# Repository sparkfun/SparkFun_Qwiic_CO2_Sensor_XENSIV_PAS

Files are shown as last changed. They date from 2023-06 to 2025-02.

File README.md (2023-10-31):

SparkFun Photoacoustic Spectroscopy CO2 Sensor - PASCO2V01 (Qwiic) 
========================================

SparkFun Photoacoustic Spectroscopy CO2 Sensor - PASCO2V01 (Qwiic) (https://www.sparkfun.com/products/22956)

[*SparkFun Photoacoustic Spectroscopy CO2 Sensor - PASCO2V01 (Qwiic) (SEN-22956)*](https://www.sparkfun.com/products/22956)

The SparkFun Photoacoustic Spectroscopy CO<sub>2</sub> Sensor features the XENSIV<sup>&trade;</sup> PASCO2V01 sensor package from Infineon<sup>&copy;</sup>. The sensor measures highly-accurate CO<sub>2</sub> data in direct parts-per-million (ppm) format over I<sup>2</sup>C, UART and PWM. The PAS CO2 employs a photoacoustic spectroscopy measurement system that combines narrow-band filtered IR light and a highly sensitive microphone inside the sensing cavity to measure CO<sub>2</sub> concentrations from 0 to 32,000 ppm with a best accuracy of &plusmn;(30ppm + 3%) when reading between 400 ppm and 5,000 ppm. It also includes a microcontroller that converts the data into direct ppm readout over any of the three communication interfaces. The IR emitter on the PAS CO2 requires a 12V supply so the board includes a AP3012 boost regulator with a series of decoupling capacitors to output a clean 12V from the 3.3V sourced through a Qwiic connection.

Repository Contents
-------------------

* **/Documentation** - Data sheets, additional product information
* **/Firmware** - Example code 
* **/Hardware** - Eagle design files (.brd, .sch)
* **/Production** - Production panel files (.brd)
* **/docs** -  Documentation files for the Photoacoustic Spectroscopy CO2 Sensor - PASCO2V01 (Qwiic) 

Documentation
--------------
* **[Library](https://github.com/Infineon/arduino-pas-co2-sensor)** - Arduino library for the XENSIV PAS CO2 Sensor.
* **[Hookup Guide](https://sparkfun.github.io/SparkFun_Qwiic_CO2_Sensor_XENSIV_PAS)** - Basic hookup guide for the Photoacoustic Spectroscopy CO2 Sensor - PASCO2V01 (Qwiic).

Product Versions
----------------
* [SEN-22956](https://www.sparkfun.com/products/22956) - Initial release of the SparkFun Photoacoustic Spectroscopy CO2 Sensor - PASCO2V01 (Qwiic) 

License Information
-------------------

This product is _**open source**_! 

Please review the LICENSE.md file for license information. 

If you have any questions or concerns on licensing, please contact technical support on our [SparkFun forums](https://forum.sparkfun.com/viewforum.php?f=152).

Distributed as-is; no warranty is given.

- Your friends at SparkFun.

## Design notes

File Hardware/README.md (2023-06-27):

SparkFun <PRODUCT NAME> Design Files
=====================================

The .sch and .brd files hare are Eagle CAD schematic and PCB design files from SparkFun Electronics.
A freeware version of Autodesk Eagle can be found [here](https://www.autodesk.com/products/eagle/free-download).

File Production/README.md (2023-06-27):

SparkFun <PRODUCT NAME> Production Files
=========================================

These are the production files SparkFun uses for printing PCBs.

License Information
-------------------
This product is open source! 

The hardware is released under [Creative Commons ShareAlike 4.0 International](https://creativecommons.org/licenses/by-sa/4.0/).

Please use, reuse, and modify these files as you see fit. Please maintain attribution to SparkFun Electronics and release anything derivative under the same license.

Distributed as-is; no warranty is given.

- Your friends at SparkFun.

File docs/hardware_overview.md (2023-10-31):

---
icon: material/cog
---

Let's take a closer look at the XENSIV™ PAS CO<sub>2</sub> sensor and other hardware present on this Qwiic breakout.

## XENSIV PAS CO2 Sensor

The XENSIV PAS CO2 sensor from Infineon utilizes a photoacoustic spectroscopy gas measurement system to accurately measure CO<sub>2</sub> concentration in a very stable sensing environment. 

<figure markdown>
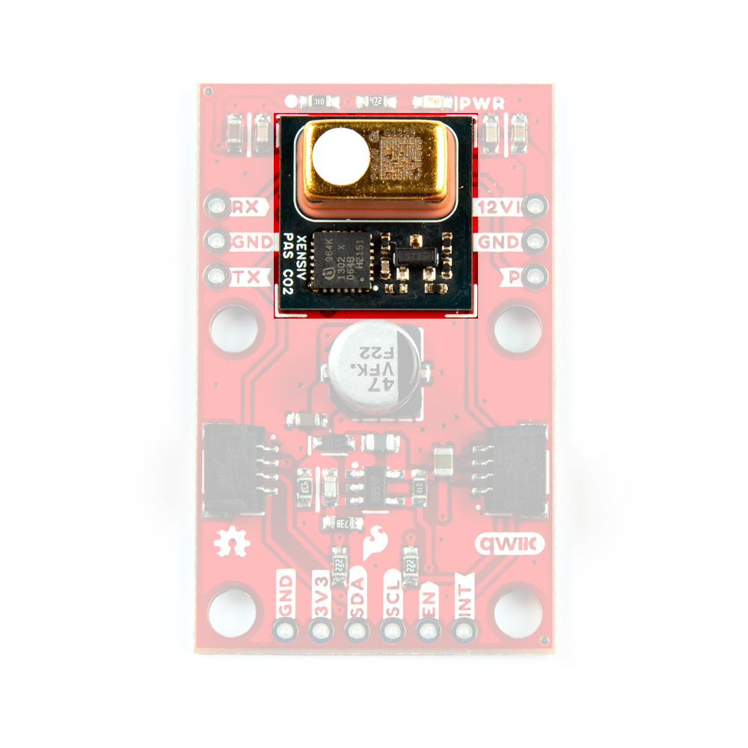
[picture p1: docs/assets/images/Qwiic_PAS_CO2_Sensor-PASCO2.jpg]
Highlighting PAS CO2 Sensor package.

</figure>

Photoacoustic spectroscopy uses a combination of narrow-band filtered IR light and MEMS microphone to measure CO<sub>2</sub> molecule concentration with high accuracy. The PAS CO<sub>2</sub> package includes an on-board microcontroller that parses the data recorded and converts it into direct parts per million (ppm) output to either UART, I<sup>2</sup>C, or pulse width modulation (PWM). For a complete overview of the PAS CO2, refer to the [datasheet](./assets/component_documentation/Infineon-PASCO2V01-DataSheet-v01_03-DataSheet-v01_03-EN.pdf).

You may be wondering what photoacoustic spectroscopy means. Photoacoustic measuring uses light (photo) and sound/vibrations (acoustic) in tandem to measure the the photoacoustic effect when energy is absorbed by particles. The sensor shines a specific frequency of IR light that CO<sub>2</sub> molecules absorb causing them to heat up, expand and release a pressure wave (sound) wave that the MEMS microphone picks up. This data is then processed and output in human-readable concentrations in PPM. This is just a quick and basic explanation of photoacoustic spectroscopy used in the PAS CO2 sensor. For detailed information, refer to Invensense's [product brief](https://www.infineon.com/cms/en/product/sensor/co2-sensors/#!?fileId=5546d4626b2d8e69016b69ba27c958c1) for the sensor.

The PAS CO2 has three operating modes: Idle, Continuous, and Single-Shot. In idle mode the sensor is inactive and does not take any measurements. In continuous mode the sensor takes periodic measurements and returns to idle once the measurement sequence finishes. The measurement period is configurable from anywhere between 5 to 4095 seconds. In single-shot mode the sensor enters a single measurement period and then returns to idle mode. 

<table>
    <tr>
        <th>Parameter</th>
        <th>Units</th>
        <th>Min</th>
        <th>Typ</th>
        <th>Max</th>
        <th>Notes</th>
    </tr>
    <tr>
        <td>CO<sub>2</sub> Output Range</td>
        <td>ppm</td>
        <td>0</td>
        <td>-</td>
        <td>32,000</td>
        <td></td>
    </tr>
    <tr>
        <td>CO<sub>2</sub> Measurement Accuracy</td>
        <td>ppm</td>
        <td>-</td>
        <td>&plusmn;(30 + 3%)</td>
        <td>-</td>
        <td>Accuracy when measuring between 400ppm and 5,000ppm.</td>
    </tr>
    <tr>
        <td>Ambient Temperature Range</td>
        <td>&deg;C</td>
        <td>0</td>
        <td>-</td>
        <td>50</td>
        <td></td>
    </tr>
    <tr>
        <td>Relative Humidity Range</td>
        <td>%RH</td>
        <td>0</td>
        <td>-</td>
        <td>85</td>
        </td></td>
    </tr>
    <tr>
        <td>CO<sub>2</sub> Sampling Time</td>
        <td>s</td>
        <td>5</td>
        <td>60</td>
        <td>4095</td>
        <td></td>
    </tr>
</table>

## Power & Boost Circuit

The PAS CO2 uses two input voltages, <b>12V</b> for the IR emitter and <b>3.3V</b> for the microcontroller and other components. This breakout has a AP3012 boost regulator to step up <b>3.3V</b> from the Qwiic connectors to <b>12V</b> along with a series of decoupling capacitors to ensure the IR emitter gets a clean supply voltage. The breakout also has PTH pins for both supply voltage if users prefer to power the sensor from a dedicated power supply. If you select this option, ensure both voltages fall within the supply range for each input (VDD3.3: <b>3V</b>-<b>3.6V</b> and VDD12: <b>10.8V</b>-<b>13.2V</b>).

## Communication Interfaces & Pinout

We designed this board to set the PAS CO2 to communicate by I<sup>2</sup>C by default but have included PTH pins for both the UART and PWM interfaces along with solder jumpers to enable/disable all three options.

<figure markdown>
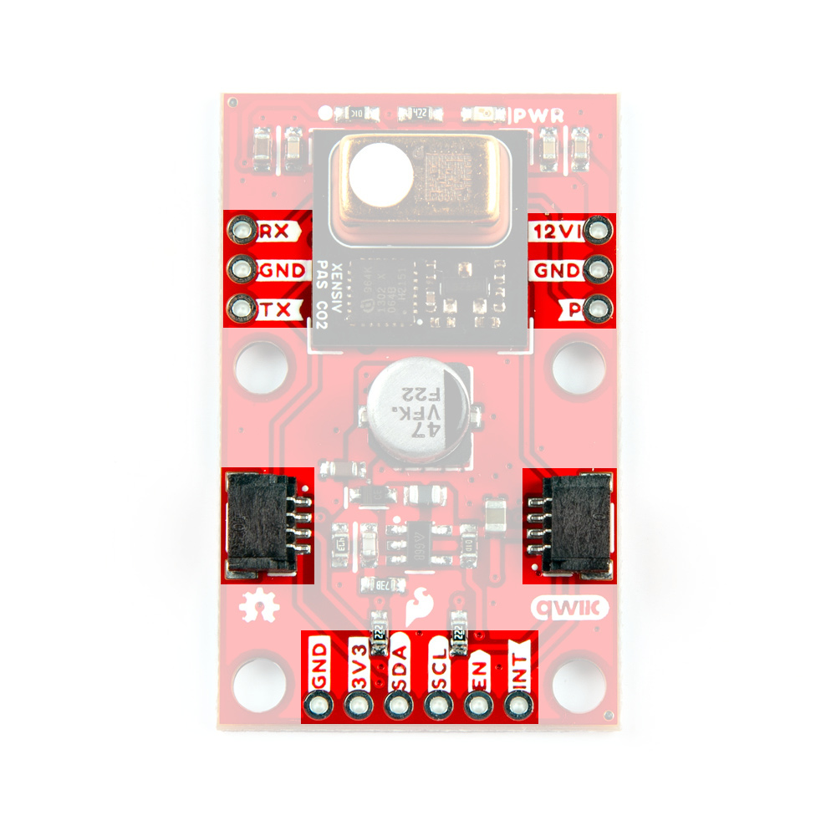
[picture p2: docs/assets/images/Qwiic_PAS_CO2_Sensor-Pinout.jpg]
Highlighting Qwiic and PTH headers.

</figure>

### Qwiic/I<sup>2</sup>C

The board routes the PAS CO2's I<sup>2</sup>C interface to a pair of Qwiic connectors as well as 0.1"-spaced plated through-hole (PTH) headers. This header also includes the PAS CO2's Interrupt pin, the AP3012 boost regulator's Enable pin, as well as connections to <b>3.3V</b> and <b>GND</b>. The PAS CO2's unshifted 7-bit I<sup>2</sup>C address is <b>0x28</b>.

The Interrupt pin can function as a standard hardware interrupt for alarm thresholds, data ready, and sensor busy statuses but also is configurable to act as an early measurement start notification. In this mode, the interrupt pin enters an active state (set to either active-high or active-low) roughly one second before a measurement period which can be tied to the enable pin for the LM62421 boost regulator. The interrupt turns this power supply on for roughly 0.2s at the start of the measurement period and again at the end. The design of the board has both this pin and the boost regulator's enable pin next to each other so users can tie them to each other to turn on the boost regulator just before measurement occurs to help conserve power.

### UART

The board routes the TX and RX pins to one side of the board along with a Ground PTH for voltage reference if needed. This interface is disabled by default and requires adjusting the PSEL jumper on the back of the board. Read on to the Solder Jumpers section for more information about enabling UART. 

### PWM

The PAS CO2's PWM interface is routed to the oppposite side of the board from the UART and also includes a Ground PTH for voltage reference. This interface is also disabled by default and can be enabled by adjusting the PWM jumper on the back of the board. Read on to the Solder Jumpers section for more information on enabling PWM output.

## Power LED

The lone LED on this board labeled <b>PWR</b> indicates when the <b>3.3V</b> circuit is powered.

<figure markdown>
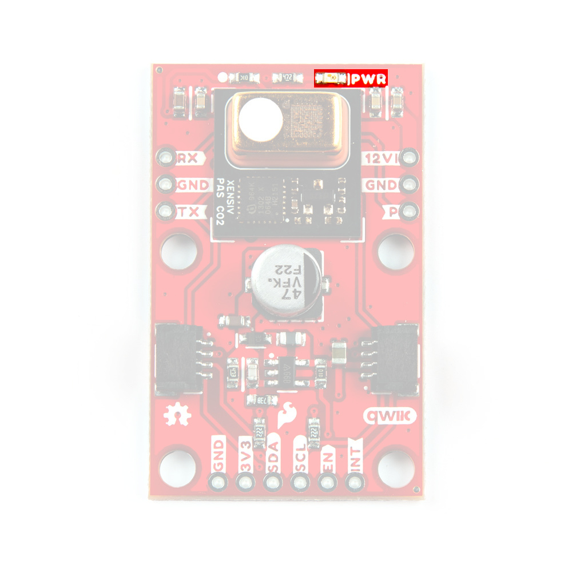
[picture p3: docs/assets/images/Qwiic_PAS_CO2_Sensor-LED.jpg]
Highlighting the Power LED.

</figure>

## Solder Jumpers

The breakout has four solder jumpers labeled <b>PWR</b>, <b>PSEL</b>, <b>PWM</b>, and <b>I<sup>2</sup>C</b>.

<figure markdown>
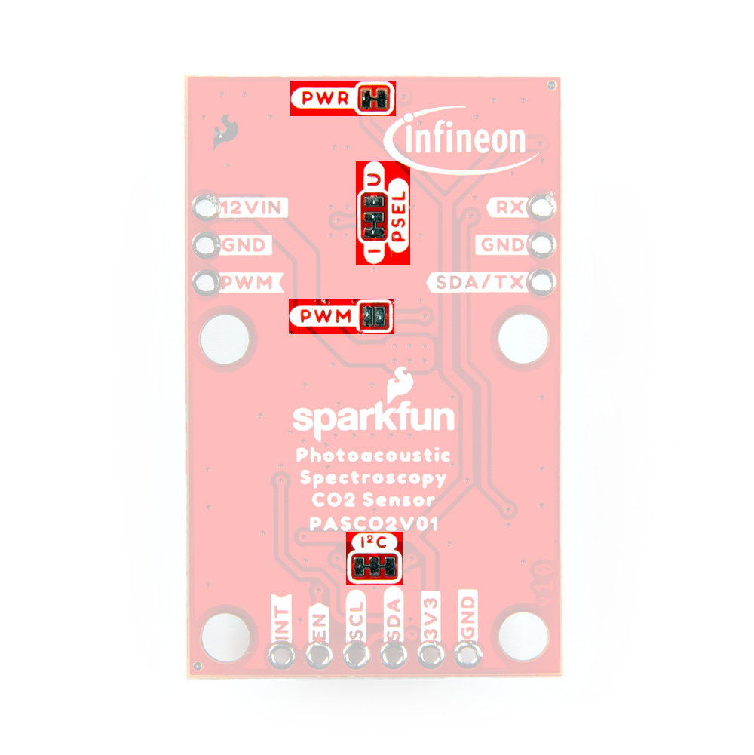
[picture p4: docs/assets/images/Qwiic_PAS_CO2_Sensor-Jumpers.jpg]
Highlighting the solder jumpers.

</figure>

* <b>PWR</b>: The PWR jumper completes the Power LED circuit. Open it to turn off the power LED to reduce the current draw of the board. 
* <b>PSEL</b>: The PSEL jumper is a three-way jumper that sets whether the PAS CO2 outputs over I<sup>2</sup>C (Default) or UART (Alternate). By default, the jumper pulls the PSEL line to Ground and enables the I<sup>2</sup>C interface indicated by the small "I" on the jumper. Severing the trace between the "I" pad and center pad and then connecting the center pad to the "U" pad switches the PAS CO2 to communicate over UART.
* <b>PWM</b>: The PWM jumper controls the PWM output through the PWM disable input pin. This jumper is OPEN by default to disable PWM through the internal pullup resistor. Close it to tie the PWM disable pin to ground and enable PWM output.
* <b>I</sup>2</sup>C</b>: Pulls the SDA/SCL lines to <b>3.3V</b> through a pair of 2.2k&ohm; resistors. Open the jumper completely to disable pullups on these lines if needed.

## Board Dimensions

This breakout measures in a bit larger than the Qwiic 1"x1" standard to accomidate the boost circuit for the IR emitter. The board measures 1"x1.6"(25.4mm x 40.64mm) with four mounting holes that fit a [4-40 screw](https://www.sparkfun.com/products/10453).

<figure markdown>
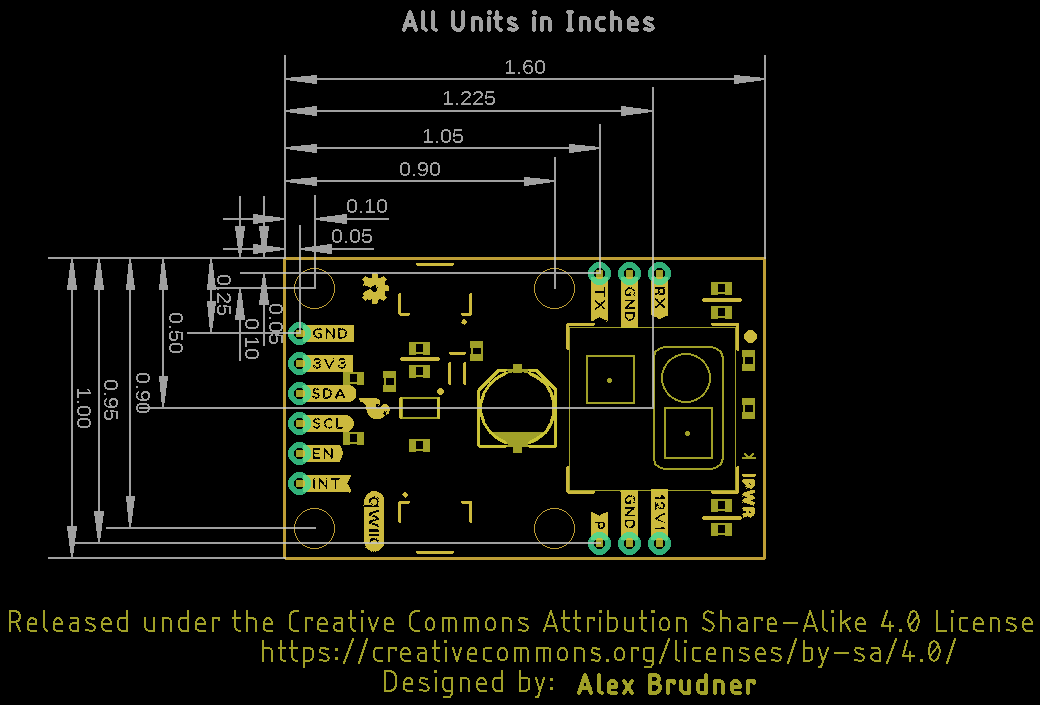
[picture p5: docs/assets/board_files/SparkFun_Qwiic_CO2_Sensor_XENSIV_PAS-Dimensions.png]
Board Dimensions.

</figure>

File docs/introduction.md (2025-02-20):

---
icon: material/book-open-page-variant
---

<div class="grid cards desc" markdown>

-    <a href="https://www.sparkfun.com/products/22956">
    **SparkFun Photoacoustic Spectroscopy CO<sub>2</sub> Sensor - PASCO2V01 (Qwiic)**<br>
    **SKU:** SEN-22956

    ---

    <figre markdown>
    Product Thumbnail
    </figure></a>

<!--
<center>
    <article class="video_desc">
    <iframe src="https://youtu.be/Du8RI4oUQT8?si=w0rP1W-pjiWIPvEG" title="Product Showcase: SparkFun Photoacoustic Spectroscopy CO<sub>2</sub> Sensor - PASCO2V01 (Qwiic)" frameborder="0" allow="accelerometer; autoplay; clipboard-write;encrypted-media; gyroscope; picture-in-picture" allowfullscreen></iframe>
    </article>
    </center>
-->
-    The SparkFun Photoacoustic Spectroscopy CO<sub>2</sub> Sensor - PASCO2V01 (Qwiic) is a breakout using the XENSIV<sup>&trade;</sup> PAS CO2 sensor package from Infineon<sup>&copy;</sup> which measures highly-accurate CO<sub>2</sub> concentrations and outputs data in direct parts-per-million (ppm) format over I<sup>2</sup>C, UART and PWN. The PAS CO2 employs a photoacoustic spectroscopy measurement system that combines narrow-band filtered IR light and a highly sensitive microphone inside the sensing cavity. The PAS CO2 measures CO<sub>2</sub> concentrations from 0 to 32,000ppm with a best accuracy of &plusmn;(30ppm +3%) when reading between 400 and 5,000ppm. It also includes and integrated microcontroller that processes and converts the data into direct ppm readout over any of the three communication interfaces. 
    This board includes a boost circuit to increase a 3.3V supply from the Qwiic connectors (or external) to 12V for the IR emitter supply voltage. This circuit includes a series of decoupling capacitors to output a clean 12V. We've also broken out all of the pins from the PAS CO2 package to 0.1"-spaced PTH headers so users have full access to all of the sensor's features.

    <center>
    [Purchase from SparkFun :fontawesome-solid-cart-plus:{ .heart }](https://www.sparkfun.com/products/22956){ .md-button .md-button--primary }
    </center>

</div>

In this guide we'll go over the hardware on this Qwiic breakout, how to assemble it into a circuit, and how to install and use Infineon's XENSIV PAS CO2 Arduino Library to configure and interact with the sensor.

## Required Materials

To follow along with this guide you will need a microcontroller to communicate with this breakout. Below are a few options that come Qwiic-enabled out of the box:

<div class="grid cards" markdown>

-   <a href="https://www.sparkfun.com/products/19177">

    <figure markdown>
    SparkFun IoT RedBoard - ESP32 Development Board
    </figure>
    </a>
    ---
    <a href="https://www.sparkfun.com/products/19177">
    **SparkFun IoT RedBoard - ESP32 Development Board**<br>
    DEV-20168
    </a>

-   <a href="https://www.sparkfun.com/products/18158">
    
    <figure markdown>
    SparkFun RedBoard Plus
    </figure>
    </a>
    ---
    <a href="https://www.sparkfun.com/products/18158">
    **SparkFun RedBoard Plus**<br>
    DEV-18158
    </a>

-   <a href="https://www.sparkfun.com/products/15574">
    
    <figure markdown>
    SparkFun Thing Plus - Artemis
    </figure>
    </a>
    ---
    <a href="https://www.sparkfun.com/products/15574">
    **SparkFun Thing Plus - Artemis**<br>
    DEV-18158
    </a>

-   <a href="https://www.sparkfun.com/products/20168">

    <figure markdown>
    SparkFun Thing Plus - ESP32 WROOM (USB-C)
    </figure>
    </a>
    ---
    <a href="https://www.sparkfun.com/products/20168">
    **SparkFun Thing Plus - ESP32 WROOM (USB-C)**<br>
    DEV-20168
    </a>
</div>

If your chosen microcontroller is not already Qwiic-enabled, you can add that functionality with one or more of the following items:

<div class="grid cards" markdown>

-   <a href="https://www.sparkfun.com/products/15081">

    <figure markdown>
    SparkFun Qwiic Cable Kit
    </figure>
    </a>
    ---
    <a href="https://www.sparkfun.com/products/15081">
    **SparkFun Qwiic Cable Kit**<br>
    KIT-15081
    </a>

-   <a href="https://www.sparkfun.com/products/14495">
    
    <figure markdown>
    SparkFun Qwiic Adapter
    </figure>
    </a>
    ---
    <a href="https://www.sparkfun.com/products/14495">
    **SparkFun Qwiic Adapter**<br>
    DEV-14495
    </a>

-   <a href="https://www.sparkfun.com/products/14352">
    
    <figure markdown>
    SparkFun Qwiic Shield for Arduino
    </figure>
    </a>
    ---
    <a href="https://www.sparkfun.com/products/14352">
    **SparkFun Qwiic Shield for Arduino**<br>
    DEV-14352
    </a>

-   <a href="https://www.sparkfun.com/products/16790">

    <figure markdown>
    SparkFun Qwiic Shield for Thing Plus
    </figure>
    </a>
    ---
    <a href="https://www.sparkfun.com/products/16790">
    **SparkFun Qwiic Shield for Thing Plus**<br>
    DEV-16790
    </a>
</div>

You will also need at least one Qwiic cable to connect your breakout to your microcontroller:

<div class="grid cards" markdown>

-   <a href="https://www.sparkfun.com/products/17259">

    <figure markdown>
    Flexible Qwiic Cable - 100mm)
    </figure>
    </a>
    ---
    <a href="https://www.sparkfun.com/products/17259">
    **Flexible Qwiic Cable - 100mm**<br>
    PRT-17259
    </a>

-   <a href="https://www.sparkfun.com/products/17260">
    
    <figure markdown>
    Qwiic Cable - 50mm
    </figure>
    </a>
    ---
    <a href="https://www.sparkfun.com/products/17260">
    **Flexible Qwiic Cable - 50mm**<br>
    PRT-17260
    </a>

-   <a href="https://www.sparkfun.com/products/17257">
    
    <figure markdown>
    Flexible Qwiic Cable - 500mm
    </figure>
    </a>
    ---
    <a href="https://www.sparkfun.com/products/17257">
    **Flexible Qwiic Cable - 500mm**<br>
    PRT-17257
    </a>

-   <a href="https://www.sparkfun.com/products/17261">

    <figure markdown>
    Flexible Qwiic Cable - Female Jumper (4-pin)
    </figure>
    </a>
    ---
    <a href="https://www.sparkfun.com/products/17261">**Flexible Qwiic Cable - Female Jumper (4-pin)**<br>
    CAB-17261
    </a>
</div>

## Optional Materials

If you prefer a soldered connection for I<sup>2</sup>C, prefer to use either the UART or PWM interfaces, or want to follow along with the Early Measurments Example later in this guide, you may need some of the products listed below:

<div class="grid cards" markdown align="center">

-   <a href="https://www.sparkfun.com/products/116">

    <figure markdown>
    Break Away Headers - Straight)
    </figure>
    </a>
    ---
    <a href="https://www.sparkfun.com/products/116">
    **Break Away Headers - Straight**<br>
    PRT-00116
    </a>

-   <a href="https://www.sparkfun.com/products/14681">
    
    <figure markdown>
    SparkFun Beginner Tool Kit
    </figure>
    </a>
    ---
    <a href="https://www.sparkfun.com/products/14681">
    **SparkFun Beginner Tool Kit**<br>
    TOL-14681
    </a>

-   <a href="https://www.sparkfun.com/products/9200">
    
    <figure markdown>
    Hobby Knife
    </figure>
    </a>
    ---
    <a href="https://www.sparkfun.com/products/9200">
    **Hobby Knife**<br>
    TOL-09200
    </a>

-   <a href="https://www.sparkfun.com/products/14579">

    <figure markdown>
    Chip Quik No-Clean Flux Pen - 10mL
    </figure>
    </a>
    ---
    <a href="https://www.sparkfun.com/products/14579">**Chip Quik No-Clean Flux Pen - 10mL**<br>
    CAB-14579
    </a>
</div>

## Suggested Reading

We designed this board for integration into SparkFun's Qwiic connect system.  Click on the banner below to learn more about the [SparkFun Qwiic Connect System](https://www.sparkfun.com/qwiic).

<div style="text-align: center">
<table>
  <tr>
   <td>
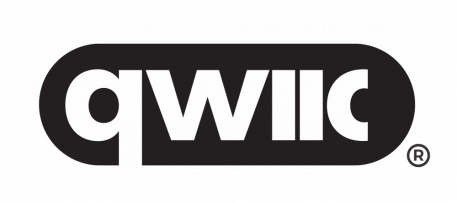
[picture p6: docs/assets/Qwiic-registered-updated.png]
Qwiic Connect System Click to learn more about the Qwiic Connect System!
   <div style="text-align: center"></div>
   </td>
  </tr>
  <tr>
    <td><div style="text-align: center"><i><a href="https://www.sparkfun.com/qwiic">Qwiic Connect System</a></i></div></td>
  </tr>
</table>
</div>

Before getting started with this Hookup Guide, you may want to read through the tutorials below if you are not familiar with the concepts covered in them or want a refresher. If you are using either of the Qwiic Shields linked above, we recommend reading through their respective Hookup Guides before continuing with this tutorial:

<div class="grid cards hide col-4" markdown align="center">

-   <a href="https://learn.sparkfun.com/tutorials/8">
    <figure markdown>
    Serial Communication
    </figure>
    </a>
    <a href="https://learn.sparkfun.com/tutorials/8">**Serial Communication**
    </a>

-   <a href="https://learn.sparkfun.com/tutorials/82">
    <figure markdown>
    I2C
    </figure>
    </a>
    <a href="https://learn.sparkfun.com/tutorials/82">**I2C**
    </a>

-   <a href="https://learn.sparkfun.com/tutorials/62">
    <figure markdown>
    Logic Levels
    </figure>
    </a>
    <a href="https://learn.sparkfun.com/tutorials/62">**Logic Levels**
    </a>

-   <a href="https://learn.sparkfun.com/tutorials/61">
    <figure markdown>
    Installing Arduino IDE
    </figure>
    </a>
    <a href="https://learn.sparkfun.com/tutorials/61">**Installing Arduino IDE**
    </a>

-   <a href="https://learn.sparkfun.com/tutorials/15">
    <figure markdown>
    Installing an Arduino Library
    </figure>
    </a>
    <a href="https://learn.sparkfun.com/tutorials/15">**Installing an Arduino Library**
    </a>

-   <a href="https://learn.sparkfun.com/tutorials/112">
    <figure markdown>
    Serial Terminal Basics
    </figure>
    </a>
    <a href="https://learn.sparkfun.com/tutorials/112">**Serial Terminal Basics**
    </a>

-   <a href="https://learn.sparkfun.com/tutorials/664">
    <figure markdown>
    How to Work with Jumper Pads and PCB Traces
    </figure>
    </a>
    <a href="https://learn.sparkfun.com/tutorials/664">**How to Work with Jumper Pads and PCB Traces**
    </a>

-   <a href="https://learn.sparkfun.com/tutorials/684">
    <figure markdown>
    Qwiic Shield for Arduino & Photon Hookup Guide
    </figure>
    </a>
    <a href="https://learn.sparkfun.com/tutorials/684">**Qwiic Shield for Arduino & Photon Hookup Guide**
    </a>

-   <a href="https://learn.sparkfun.com/tutorials/1107">
    <figure markdown>
    Qwiic Shield for Thing Plus Hookup Guide
    </figure>
    </a>
    <a href="https://learn.sparkfun.com/tutorials/1107">**Qwiic Shield for Thing Plus Hookup Guide**
    </a>
</div>

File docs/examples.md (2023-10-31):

---
icon: simple/arduino
---

## Example 1 - Continuous Mode

The first example demonstrates how to initialize the sensor over I<sup>2</sup>C to measure CO<sub>2</sub> data in Continuous Mode and print it out over serial. Open the example by navigating to <b>File</b> > <b>Examples</b> > <b>XENSIV PAS CO2</b> > <b> <b>continuous-mode</b>. After opening the example, select your Board and Port (in our case, SparkFun RedBoard IoT), and click "Upload". Open the [serial terminal](https://learn.sparkfun.com/tutorials/terminal-basics/arduino-serial-monitor-windows-mac-linux) with the baud set to <b>9600</b> and you should see the same as the screenshot below:

<figure markdown>
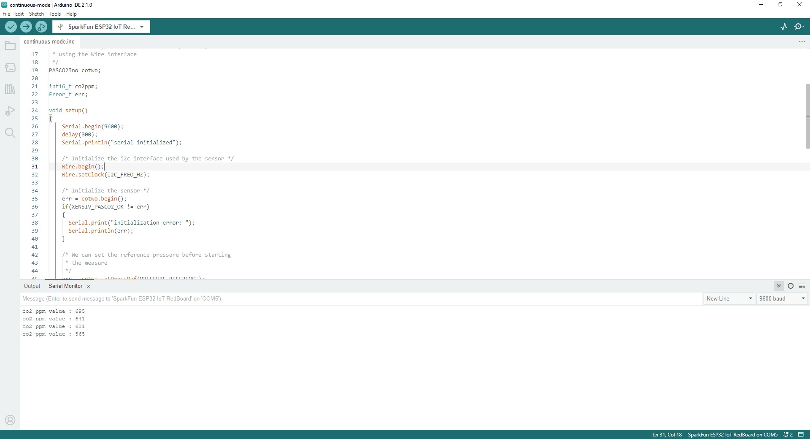
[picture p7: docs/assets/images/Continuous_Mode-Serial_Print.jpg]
Screenshot of serial printout from continuous mode example.

</figure>

## Example 2 - Boost Regulator Early Notification

The second example follows the assembly step in the Hardware Assembly section tying the PAS CO2's INT pin to the boost regulator's EN pin to control power for the regulator during measurements. This is a custom example we wrote so you'll need to get it from the [GitHub Repository](https://github.com/sparkfun/SparkFun_Qwiic_CO2_Sensor_XENSIV_PAS) or by copying the code below into a blank sketch:

??? "Early Measurement Example"

    ```
     --8<-- "https://raw.githubusercontent.com/sparkfun/SparkFun_Qwiic_CO2_Sensor_XENSIV_PAS/main/Firmware/Examples/Example01_EarlyMeasurementStartInterrupt/Example01_EarlyMeasur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"
    ```

Select your board and port and upload the example. After the uploade completes, open the serial terminal with the baud set to <b>115200</b> and you should see a printout similar to the one below with CO<sub>2</sub> measurements printing every ten seconds:

<figure markdown>
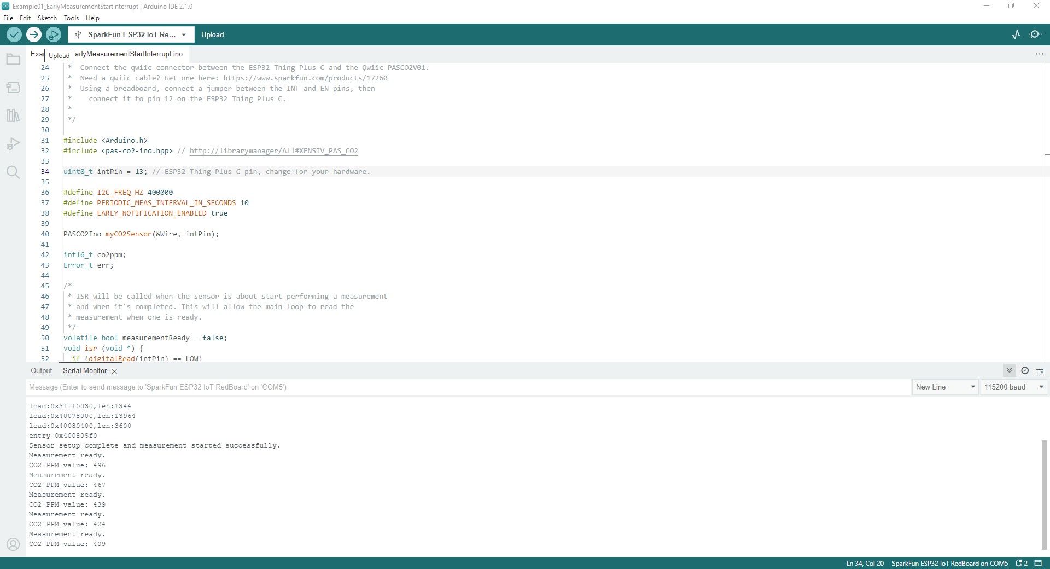
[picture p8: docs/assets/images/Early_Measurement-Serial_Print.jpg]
Screenshot of serial printout from early measurement example.

</figure>

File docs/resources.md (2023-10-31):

For more information about the XENSIV PAS CO2 sensor and this breakout, take a look at the resources below:

* [Schematic](./assets/board_files/SparkFun_Qwiic_CO2_Sensor_XENSIV_PAS.pdf)
* [Eagle Files](./assets/board_files/SparkFun_Qwiic_CO2_Sensor_XENSIV_PAS.zip)
* [Board Dimensions](./assets/board_files/SparkFun_Qwiic_CO2_Sensor_XENSIV_PAS-Dimensions.png)
* [Datasheet](./assets/component_documentation/Infineon-PASCO2V01-DataSheet-v01_03-DataSheet-v01_03-EN.pdf) (PASCO2V01)
* [Datasheet](./assets/component_documentation/AP3012.pdf) (AP3012 Boost Regulator)
* [Design-In Guidelines](./assets/component_documentation/Infineon-PAS_CO2_General_Design-In_Guideline.docx.-ApplicationNotes-v01_02-EN.pdf)
* [Low Power App Note](./assets/component_documentation/Infineon-XENSIV_PAS_CO2_lowpower_applications-ApplicationNotes-v01_01-EN.pdf)
* [PAS CO2 FCS & ABOC Compensation App Note](./assets/component_documentation/Infineon-AN_FCS_ABOC_XENSIV_PASCO2_2-ApplicationNotes-v01_04-EN.pdf)
* [GitHub Repository](https://github.com/sparkfun/SparkFun_Qwiic_CO2_Sensor_XENSIV_PAS)
* [XENSIV Arduino Library Repository](https://github.com/Infineon/arduino-pas-co2-sensor)

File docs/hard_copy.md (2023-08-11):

---
icon: fontawesome/solid/print
---

Need to download or print our hookup guide?

* [Print :fontawesome-solid-print:](../single_page) (Single-Page View)
    * To save as a `*.pdf` file, select the **Printer** or **Destination** labeled ++"Save as PDF"++. *(Instructions will vary based on the browser)*

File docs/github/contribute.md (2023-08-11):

# Help Improve the Experience!
Spot an improvement opportunity? Feel free to contribute to our open-source design and documentation. 

## Enhance our Documentation
All of this documentation can be modified by you! Please help us make it better.

* These pages are contained in the [`docs` folder](https://github.com/sparkfun/SparkFun_Qwiic_CO2_Sensor_XENSIV_PAS/tree/main/docs) of the [SparkFun Photoacoustic Spectroscopy CO<sub>2</sub> Sensor - PASCO2V01 (Qwiic)](https://github.com/sparkfun/SparkFun_Qwiic_CO2_Sensor_XENSIV_PAS) repository.

### Submit a Correction
1. Fork this repo
2. Add your corrections or improvements to the markdown file
3. File a pull request with your changes, and enjoy making the ~~words~~ ~~worlds~~ world a better place.
	* Once received, the documentation specialist will automatically be notified.
	* We will review your suggested improvements to make sure they are correct and fit within our documentation standards.

## Upgrade our Hardware Design
All of our designs are open-source! Please help us make it better.

* Our board design files are contained in the [`Hardware` folder](https://github.com/sparkfun/SparkFun_Qwiic_CO2_Sensor_XENSIV_PAS/tree/main/Hardware) of the [SparkFun Photoacoustic Spectroscopy CO<sub>2</sub> Sensor - PASCO2V01 (Qwiic)](https://github.com/sparkfun/SparkFun_Qwiic_CO2_Sensor_XENSIV_PAS) repository.

### Submit a Design Improvement
1. Fork this repo
2. Add your design modifications
3. File a pull request with your changes, and enjoy making the world a better place.
	* Once received, the engineer in charge of the original design will automatically be notified.
	* We will review your suggested upgrades, if they are within our board design standards and meet our product design requirements, we will flag these changes for our next board revision.
	
	!!! note
		Please note, that even if your suggestion is accepted, these changes may not be immediate. We may have to cycle through our current product inventory first.

## Contributors
Let's provide some recognition to those who have contributed to this project!

GitHub Contributors Image
<br>


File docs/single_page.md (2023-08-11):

---
hide:
  - navigation
  - toc
icon: fontawesome/solid/scroll
---

# Introduction
--8<-- "./docs/introduction.md:5"

# Hardware Overview
--8<-- "./docs/hardware_overview.md:5"

# Hardware Assembly
--8<-- "./docs/hardware_assembly.md:5"

# Software Setup and Programming
--8<-- "./docs/software_setup.md:5"

# Example Code
--8<-- "./docs/examples.md"

# Troubleshooting Tips
--8<-- "./docs/troubleshooting.md"

# Resources:
--8<-- "./docs/resources_and_going_further.md"

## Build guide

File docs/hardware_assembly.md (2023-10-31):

---
icon: material/tools
---

Now that we're familiar with the PAS CO2 sensor and other hardware on this breakout, it's time to assemble it into a circuit.

## Qwiic Assembly

SparkFun's Qwiic system makes assembling a circuit a breeze. Simply plug the breakout into your chosen microcontroller with a Qwiic cable. After assembling your circuit, it should look similar to the photo below:

<figure markdown>
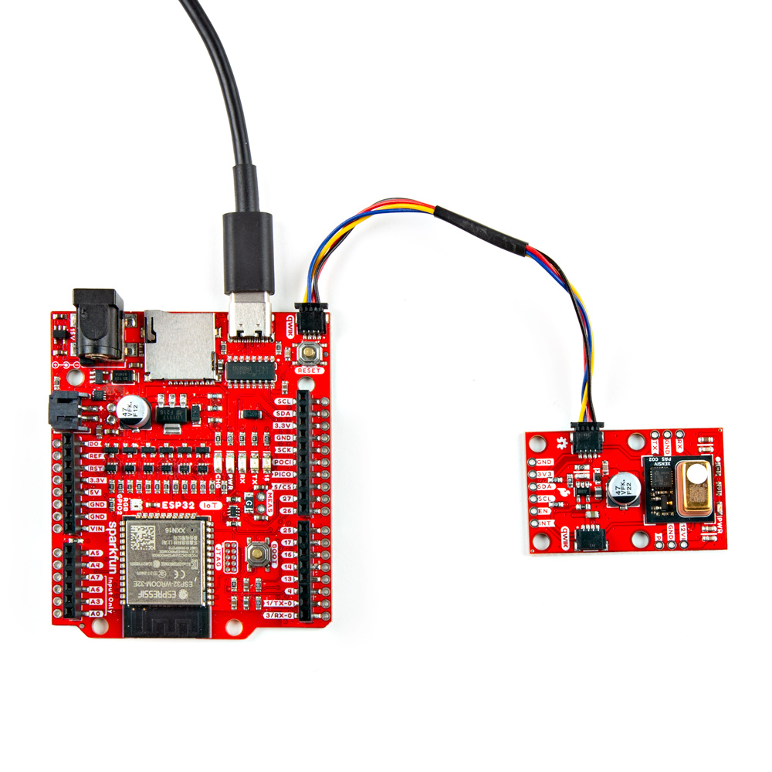
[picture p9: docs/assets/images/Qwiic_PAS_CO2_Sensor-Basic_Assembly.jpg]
Simple Qwiic circuit assembled with IoT RedBoard.

</figure>

## Soldered Assembly

Those who prefer to use either the UART or PWM interfaces or the other pins broken out on this board should solder wires or header pins to the PTH pins on the side of the board. If you're not familiar with through-hole soldering or would like a refresher, take a look at our Through-Hole Soldering Tutorial:

<div class="grid cards" markdown align="center">

-   <a href="https://learn.sparkfun.com/tutorials/5">
    <figure markdown>
    How to Solder: Through-Hole Soldering
    </figure>
    </a>
    <a href="https://learn.sparkfun.com/tutorials/5">**How to Solder: Through-Hole Soldering**
    </a>

</div>

### Boost Regulator Interrupt Assembly

The Early Measurement example in the Examples section demonstrates how to use the PAS CO2's Interrupt pin as an early measurement signal to control the boost regulator's power during measurement periods. If you want to follow along with that example you'll need to tie the INT PTH pin and EN PTH pin together. We recommend a set of [headers](https://www.sparkfun.com/products/12693) to these PTHs and bridge the EN and INT pins together using a jumper like [this](https://www.sparkfun.com/products/9044). You can also create a temporary connection between these pins with some alligator clips or through some wiring on a breadboard.

Next, connect the INT pin on the PAS CO<sub>2</sub> sensor breakout to an [interrupt capable pin]() on your development board. The example assumes the use of an ESP32 development board and sets pin 13 so adjust the wiring and code if necessary. With everything wired up on a [breadboard](), the circuit should look something similar to the photo below:

<figure markdown>
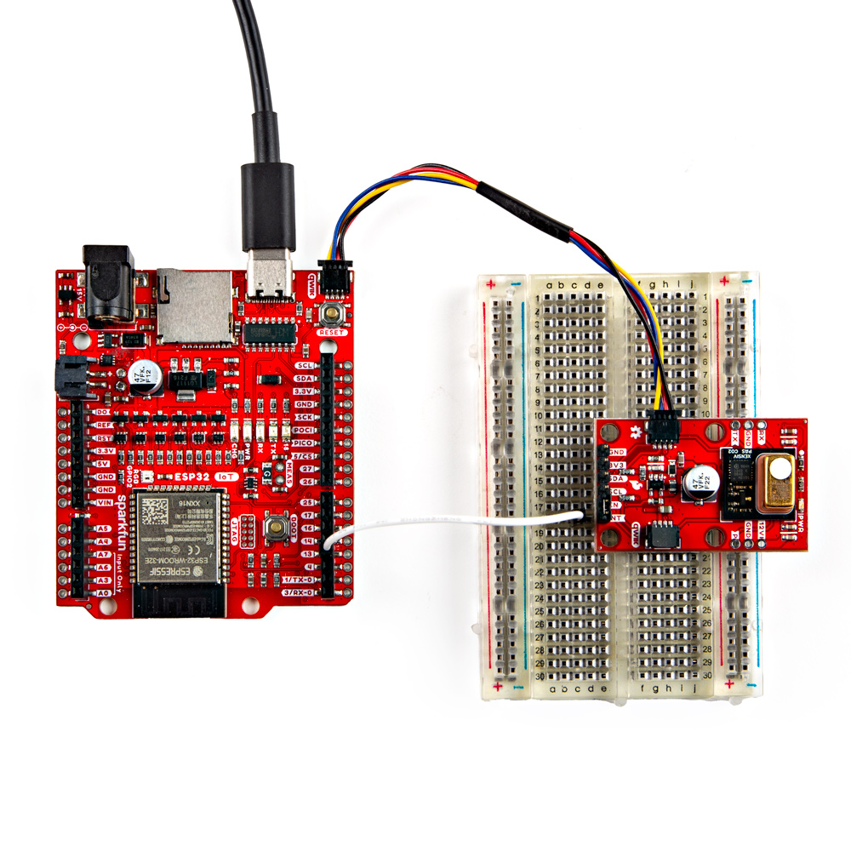
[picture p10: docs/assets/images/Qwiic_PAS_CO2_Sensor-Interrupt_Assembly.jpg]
Early measurement circuit assembly on a breadboard.

</figure>

## Calibration Procedure

The PASCO2V01 sensors require a week long calibration period, measuring every 10 seconds. During that period, the sensor *must* be outside for at least 30 minutes while taking measurements. Refer to the [Automatic baseline offset correction (ABOC) and forced compensation scheme (FCS)](./assets/component_documentation/Infineon-AN_FCS_ABOC_XENSIV_PASCO2_2-ApplicationNotes-v01_04-EN.pdf) application note for complete information about the calibration process. The graph below shows three sensors data outputs merge together during our calibration testing:

<figure markdown>
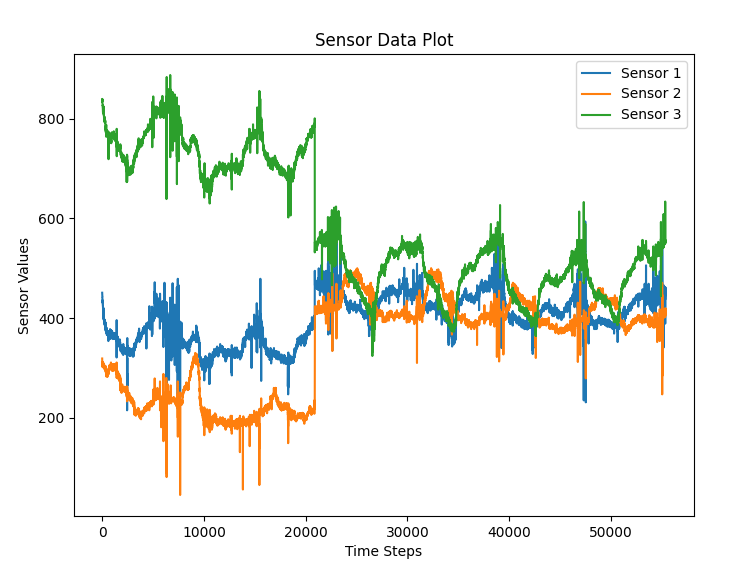
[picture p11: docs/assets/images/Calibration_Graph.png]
Sensor calibration graph.

</figure>

## Installation Recommendations

For ideal measurements, Infineon has several recommendations for installing the sensor in the final application found in this [application note](./assets/component_documentation/Infineon-PAS_CO2_General_Design-In_Guideline.docx.-ApplicationNotes-v01_02-EN.pdf). The list below outlines most of them but for complete information, refer to the app note linked above.

* Allow space above the sensor at least 12mm tall with a minimum opening size of 14mm x 14mm.
* Avoid direct airflow in front of the sensor.
* Isolate the sensor from ambient heat sources.
* Isolate the sensor from vibration sources.
* Avoid placing the sensor in direct sunlight.
* Prevent any condensation/water contact with the sensor.

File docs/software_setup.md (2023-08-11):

---
icon: simple/arduino
---

!!! attention
	If this is your first time using Arduino, please read through our tutorial on [installing the Arduino IDE](https://learn.sparkfun.com/tutorials/installing-arduino-ide). If you have not installed an Arduino library before, we recommend you check out our [installation guide](https://learn.sparkfun.com/tutorials/installing-an-arduino-library).

Infineon has written an Arduino Library for the PAS CO2 sensor to make it easy to get CO<sub>2</sub> data from the sensor along with other settings and features. Users can download the library through the Arduino Library Manager by searching for <b>"XENSIVE PAS CO2x"</b> as the screenshot below shows:

Those who prefer to manually install it can download a ZIP of the library from the [GitHub repository](https://github.com/Infineon/arduino-pas-co2-sensor) or by clicking the button below:

<center>
[XENSIV PAS CO2 Arduino Library (ZIP)](https://github.com/Infineon/arduino-pas-co2-sensor/archive/refs/heads/master.zip){ .md-button .md-button--primary }
</center>

With the library installed let's move on to looking at a few of the examples included in it.

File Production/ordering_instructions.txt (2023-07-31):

panel size, 169x96mm
PCB thickness, 1.6mm
number of layers, 2
material, TG155
soldermask color, Red
silkscreen color, White
oz copper, 1oz
finish, HASL lead free
stencils, top
pcs per panel, 12
min trace width, 0.1778mm / 0.0070in
min drill size, 0.3810mm / 0.0150in

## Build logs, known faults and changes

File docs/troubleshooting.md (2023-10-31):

## Ideal Installation Recommendations

For ideal measurements, Infineon has several recommendations for installing the sensor in the final application found in this [application note](). The list below outlines most of them but for complete information, refer to the app note linked above.

* Allow a space above the sensor at least 12mm tall with a minimum opening size of 14mm x 14mm.
* Avoid direct airflow in front of the sensor.
* Isolate the sensor from ambient heat sources.
* Isolate the sensor from vibration sources.
* Avoid placing the sensor in direct sunlight.
* Prevent any condensation/water contact with the sensor.

## Calibration Procedure

The PASCO2V01 sensors require a week long calibration period, measuring every 10 seconds. During that period, the sensor *must* be outside for at least 30 minutes while taking measurements. Refer to the [Automatic baseline offset correction (ABOC) and forced compensation scheme (FCS)](./assets/component_documentation/Infineon-AN_FCS_ABOC_XENSIV_PASCO2_2-ApplicationNotes-v01_04-EN.pdf) application note for complete information about the calibration process. The graph below shows three sensors data outputs merge together during our calibration testing:

<figure markdown>
Sensor calibration graph.
</figure>

## General Troubleshooting

!!! warning "Need Help?"
    If you need technical assistance or more information on a product that is not working as you expected, we recommend heading on over to the [SparkFun Technical Assistance](https://www.sparkfun.com/technical_assistanc) page for some initial troubleshooting.

    <center>
    [SparkFun Technical Assistance Page](https://www.sparkfun.com/technical_assistance){ .md-button .md-button--primary }
    </center>
    
    If you can't find what you need there, the [SparkFun Forums](https://forum.sparkfun.com/index.php) is a great place to search product forums and ask questions.
    
    !!! info "Account Registration Required"
        If this is your first visit to our forum, you'll need to create a [Forum Account](https://forum.sparkfun.com/ucp.php?mode=register) to post questions.

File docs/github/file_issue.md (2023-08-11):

# Did we make a mistake?

Spot something wrong? Please let us know. 

!!! attention
	This is not where customers should seek assistance on a product. If you require technical assistance or have questions about a product that is not working as expected, please head over to the [SparkFun Technical Assistance](https://www.sparkfun.com/technical_assistance) page for some initial troubleshooting.
    <center>
    [SparkFun Technical Assistance Page](https://www.sparkfun.com/technical_assistance){ .md-button .md-button--primary }
    </center>
    
    If you can't find what you need there, the [SparkFun Forums](https://forum.sparkfun.com/index.php) is a great place to search product forums and ask questions.
    
    !!! info "Account Registration Required"
        If this is your first visit to our forum, you'll need to create a [Forum Account](https://forum.sparkfun.com/ucp.php?mode=register) to search product forums and post questions.

## Discrepancies in the Documentation

All of this documentation can be modified by you! Please help us make it better.

* The documentation files for these pages are contained in the [`docs` folder](https://github.com/sparkfun/SparkFun_Qwiic_CO2_Sensor_XENSIV_PAS/tree/main/docs) of the [SparkFun Photoacoustic Spectroscopy CO<sub>2</sub> Sensor - PASCO2V01 (Qwiic)](https://github.com/sparkfun/SparkFun_Qwiic_CO2_Sensor_XENSIV_PAS) repository.

### Spot something wrong?
If a section of the documentation is incorrect, please [open an issue](https://github.com/sparkfun/SparkFun_Qwiic_CO2_Sensor_XENSIV_PAS/issues) and let us know.

### Do you have a suggested correction?
1. With a GitHub account, fork this repo
2. Add your correction(s) or improvement(s) to the markdown file(s)
3. File a pull request with your changes, and enjoy making the ~~words~~ ~~worlds~~ world a better place.
	* Once received, the documentation specialist will automatically be notified.
	* We will review your suggested improvement(s) to make sure they are correct and fit within our documentation standards.

## Problems in the Hardware Design

All of our designs are open-source! Please help us make it better.

* Our board design files are contained in the [`Hardware` folder](https://github.com/sparkfun/SparkFun_Qwiic_CO2_Sensor_XENSIV_PAS/tree/main/Hardware) of the [SparkFun Photoacoustic Spectroscopy CO<sub>2</sub> Sensor - PASCO2V01 (Qwiic)](https://github.com/sparkfun/SparkFun_Qwiic_CO2_Sensor_XENSIV_PAS) repository.

### Does something not make sense?
If part of the design is confusing, please [open an issue](https://github.com/sparkfun/SparkFun_Qwiic_CO2_Sensor_XENSIV_PAS/issues) and let us know.

### Did we forget to include an important function of the board?
* Please keep in mind that we may intentionally exclude certain functions of the board to meet our product design requirements. *(For example, our Qwiic Micro boards are intended to fit on a small board layout and only use I<sup>2</sup>C communication; therefore, we may not have the SPI and interrupt pins available for users.)*
* If part of the board's functionality is missing, please [open an issue](https://github.com/sparkfun/SparkFun_Qwiic_CO2_Sensor_XENSIV_PAS/issues) and file a feature request.

### Do you wish to contribute directly to improving the board design?
1. With a GitHub account, Fork this repo
2. Add your design improvement(s)
3. File a pull request with your changes, and enjoy making the ~~words~~ ~~worlds~~ world a better place.
	* Once received, the engineer in charge of the original design will automatically be notified.
	* We will review your suggested improvement(s), if they are within our board design standards and meet our product design requirements, we will flag these changes for our next board revision. *(Please note, that even if your suggestion is accepted, these changes may not be immediate. We may have to cycle through our current product inventory first.)*

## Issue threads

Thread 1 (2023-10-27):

Problem with format of Guides

ClarkInAz, 2023-10-27:
### Subject of the issue
Problem with overall format for Guides

### Your workbench
Firefox web browser on OSX
### Steps to reproduce
Look through the original guide by clicking on the "Getting Started" guide on https://www.sparkfun.com/products/22956
### Expected behavior
A clear explaination of HOW to get to the next page after the "background info" stuff.

### Actual behavior
FORCES first time user of this new Guide format to GUESS how to get to actual info.  Go look at one of the older "Getting Started" guides -- it's VERY CLEAR how to get to the next page!

For example, https://learn.sparkfun.com/tutorials/sparkfun-gps-rtk-dead-reckoning-zed-f9r-hookup-guide
It's BLATANTLY CLEAR how to get to the next page!

gigapod, 2023-10-30:
Hi @ClarkInAz,

Like many companies/individuals ([Arduino for example](https://arduino.github.io/arduino-cli/0.35/)) in the development board space, we’re moving to host our hookup guides/documentation on GitHub pages – using [Material MKDocs](https://squidfunk.github.io/mkdocs-material/) to generate our content.

The transition to a GitHub Pages solution provides SparkFun better tools to generate our documentation/content and more importantly reinforces our continued engagement and cooperation with the community as a whole – enabling rapid integration of community feedback, suggestions, and edits. This was difficult to impossible with our older system.

The documentation and content teams spent considerable effort in developing our new solution and are continuing to improve it going forward.

While the new solution does provide a “next page” indicator/link at the bottom of our documentation pages, your feedback is helpful for the teams as the continue to review our solution.

-Kirk

Closed 2023-10-30.

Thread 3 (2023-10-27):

Missing item in "Hardware Overview"

ClarkInAz, 2023-10-27:
### Subject of the issue
In the "Hardware Overview", under "Solder Jumpers", the I2C jumper is listed, but there's no explaination of what it does.

### Your workbench
Firefox on OSX

### Steps to reproduce
Read the "Solder Jumpers" section of the Guide.
### Expected behavior
The purpose of each of the four jumpers, PWR, PSEL, PWM, and I2C should have its own bullet describing what it does.

### Actual behavior
The bullet points for PWR, PSEL, and PWM are present, but the I2C is missing.
Although it's pretty typical that cutting the traces for the I2C disables the I2C pullup resistors, I don't have time right now to go through the schematic and verify it (not with the overhead of the new "comment" format), so won't submit a correction myself.

SFEMark, 2023-10-31:
Thanks for letting us know about this error. Your assumption is correct and it just pulls the SDA/SCL lines to 3.3V (but we all know what happens when you assume). We've updated the Hardware Overview section to add the I2C jumper description to the solder jumpers list.

Closed 2023-10-31.

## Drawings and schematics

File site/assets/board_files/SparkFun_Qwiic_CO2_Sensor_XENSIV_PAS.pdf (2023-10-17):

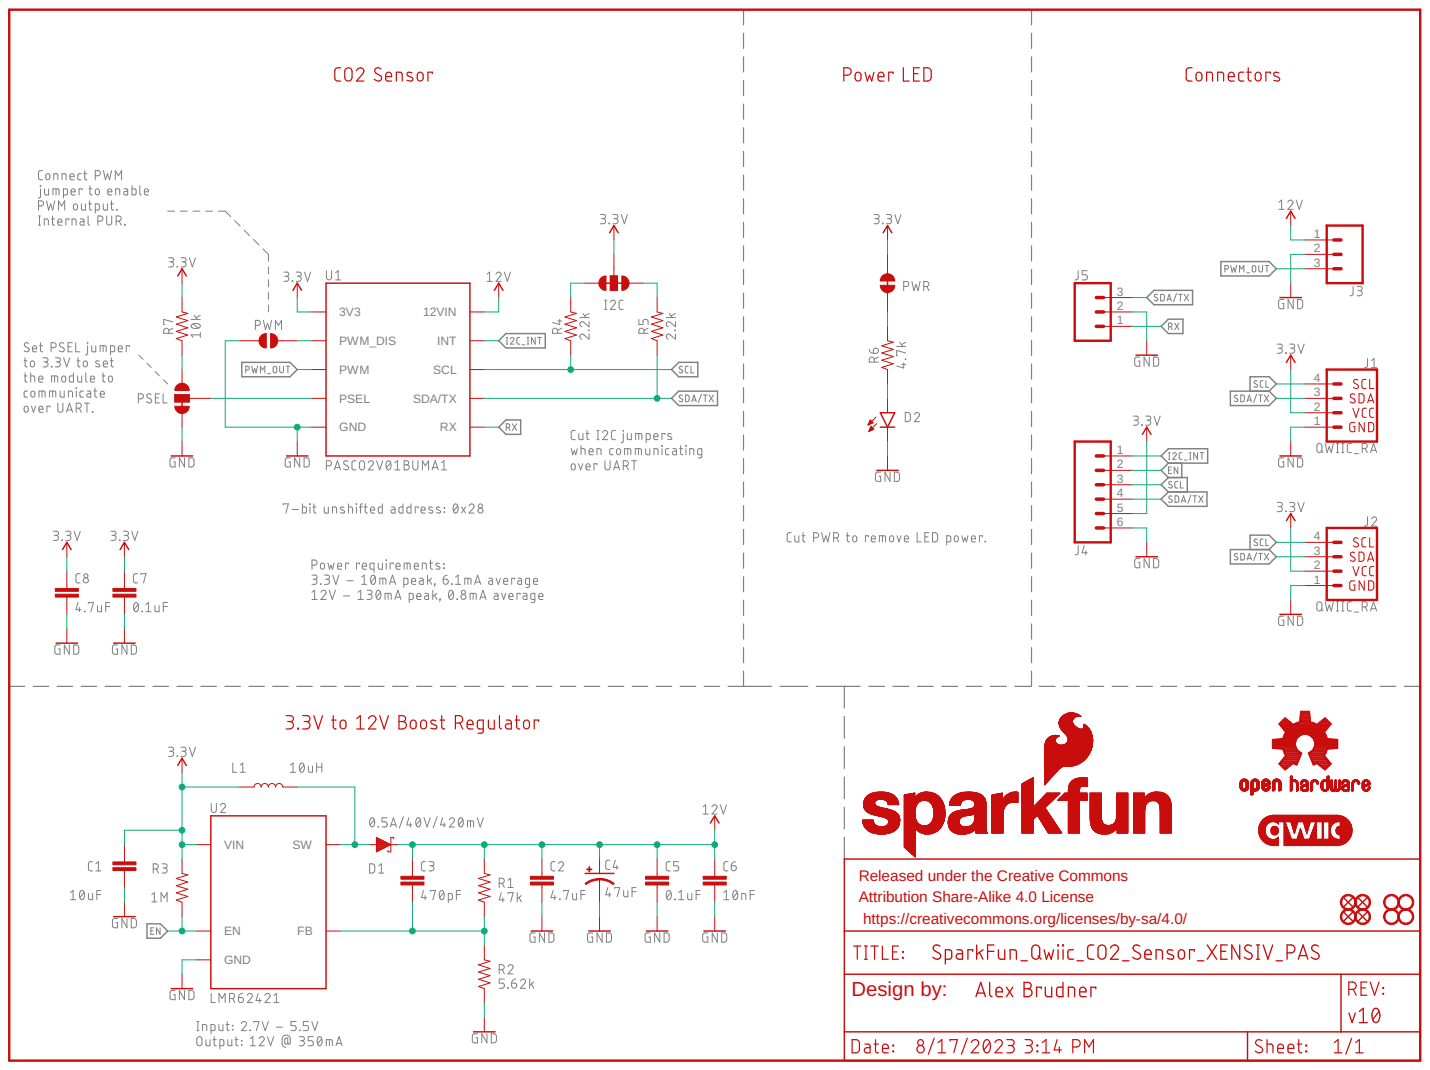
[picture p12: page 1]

INT SCL SDA/TXRX

Released under the Creative Commons Attribution Share-Alike 4.0 License

https://creativecommons.org/licenses/by-sa/4.0/

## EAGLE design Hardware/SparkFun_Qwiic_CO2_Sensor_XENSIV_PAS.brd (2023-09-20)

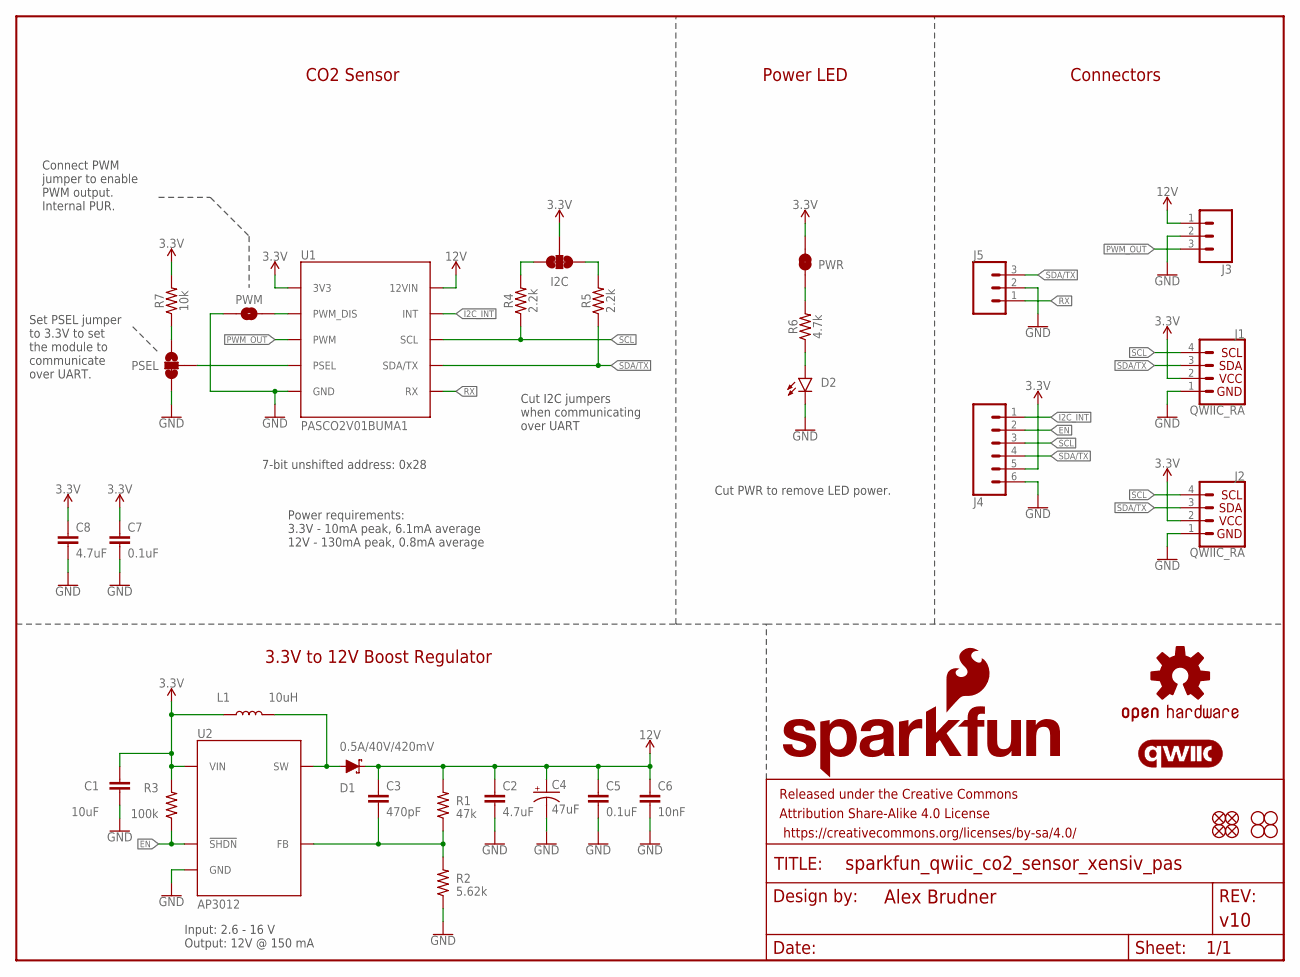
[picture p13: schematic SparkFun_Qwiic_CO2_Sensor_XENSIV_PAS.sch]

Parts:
C1: 10uF; 0805
C2, C8: 4.7uF; 0603
C3: 470pF; 0603
C4: 47uF; PANASONIC_D
C5, C7: 0.1uF; 0603
C6: 10nF; 0603
D1: 0.5A/40V/420mV; SOD-323
D2: LED-RED_0603-KB; LED-0603
FD1, FD2, FD3, FD4: FIDUCIALUFIDUCIAL; FIDUCIAL-MICRO
FRAME1: FRAME-LETTER; CREATIVE_COMMONS
H1, H2, H3, H4: STAND-OFF
I2C: JUMPER-SMT_3_2-NC_TRACE_SILK; SMT-JUMPER_3_2-NC_TRACE_SILK
J1, J2: QWIIC_RA; JST04_1MM_RA
J3, J5: CONN_031X03_NO_SILK; 1X03_NO_SILK
J4: CONN_06NO_SILK_NO_POP; 1X06_NO_SILK
L1: 10uH; 0805
LOGO1: SFE_LOGO_NAME_FLAME.1_INCH; SFE_LOGO_NAME_FLAME_.1
LOGO2: QWIIC_LOGO_5MM; QWIIC_5MM
LOGO3: OSHW-LOGOMINI; OSHW-LOGO-MINI
PSEL: JUMPER-SMT_3_1-NC_TRACE_SILK; SMT-JUMPER_3_1-NC_TRACE_SILK
PWM: JUMPER-SMT_2_NO_SILK; SMT-JUMPER_2_NO_SILK
PWR: JUMPER-SMT_2_NC_TRACE_SILK; SMT-JUMPER_2_NC_TRACE_SILK
R1: 47k; 0603
R2: 5.62k; 0603
R3: 100k; 0603
R4, R5: 2.2k; 0603
R6: 4.7k; 0603
R7: 10k; 0603
U1: PASCO2V01BUMA1; LG-MLGA-14-1_Z8B00206105
U2: AP3012; SOT95P280X145-5M

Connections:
3.3V: C1.1, C7.1, C8.1, I2C.2, J1.2, J2.2, J4.5, L1.1, PWR.2, R3.2, R7.2, U1.1 (3V3), U2.5 (VIN)
12V: C2.1, C3.1, C4.+, C5.1, C6.1, D1.C, J3.1, R1.2, U1.10 (12VIN)
EN: J4.2, R3.1, U2.4 (!SHDN!)
GND: C1.2, C2.2, C4.-, C5.2, C6.2, C7.2, C8.2, D2.C, J1.1, J2.1, J3.2, J4.6, J5.2, PSEL.3, PWM.1, R2.1, U1.6 (GND), U1.11 (GND), U1.12 (GND), U1.13 (GND), U1.14 (GND), U2.2 (GND)
I2C_INT: J4.1, U1.7 (INT)
unnamed: I2C.1, R5.2
unnamed: D1.A, L1.2, U2.1 (SW)
unnamed: I2C.3, R4.2
unnamed: C3.2, R1.1, R2.2, U2.3 (FB)
unnamed: PSEL.2, U1.8 (PSEL)
unnamed: D2.A, R6.1
unnamed: PWR.1, R6.2
unnamed: PSEL.1, R7.1
unnamed: PWM.2, U1.5 (PWM_DIS)
PWM_OUT: J3.3, U1.9 (PWM)
RX: J5.1, U1.2 (RX)
SCL: J1.4, J2.4, J4.3, R4.1, U1.3 (SCL)
SDA/TX: J1.3, J2.3, J4.4, J5.3, R5.1, U1.4 (SDA/TX)

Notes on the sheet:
3.3V to 12V Boost Regulator
CO2 Sensor
Connectors
Set PSEL jumper to 3.3V to set the module to communicate over UART.
Cut I2C jumpers when communicating over UART
Power LED
Cut PWR to remove LED power.
Input: 2.6 - 16 V Output: 12V @ 150 mA
7-bit unshifted address: 0x28
Power requirements: 3.3V - 10mA peak, 6.1mA average 12V - 130mA peak, 0.8mA average
Connect PWM jumper to enable PWM output. Internal PUR.

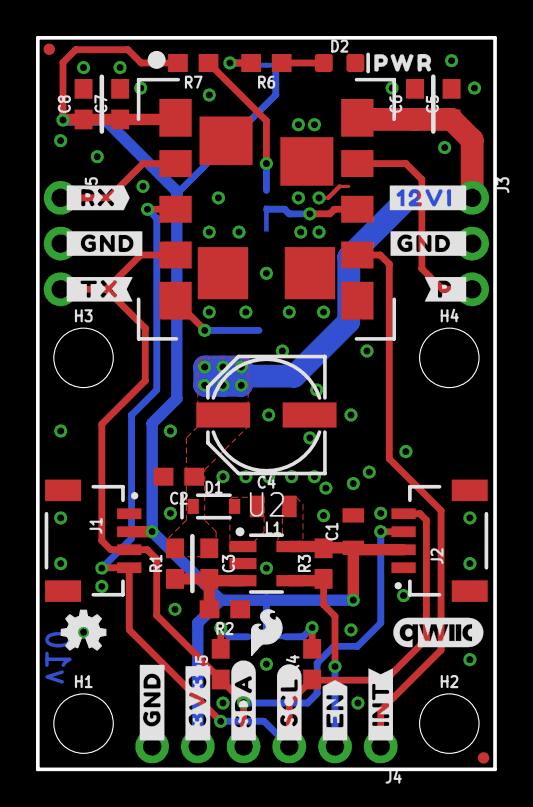
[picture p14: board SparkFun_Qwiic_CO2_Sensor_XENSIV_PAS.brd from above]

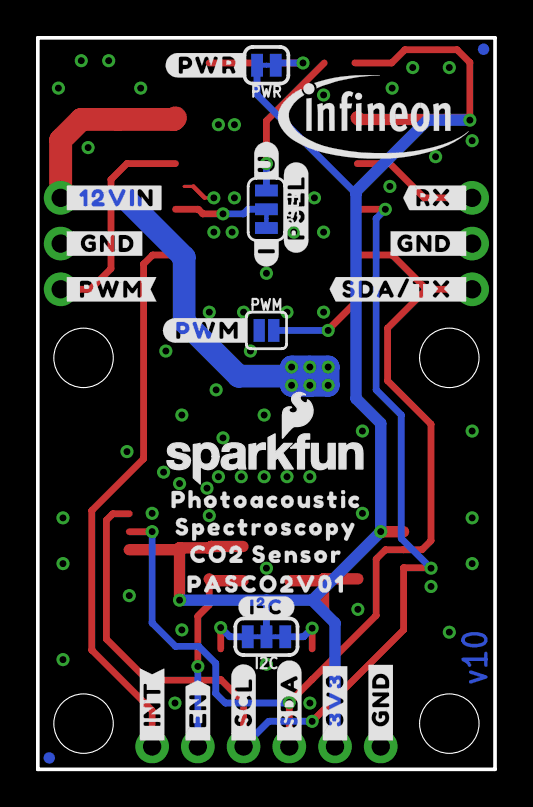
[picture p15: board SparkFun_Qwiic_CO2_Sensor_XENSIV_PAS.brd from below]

Board: 2 copper layers, 25.4 x 40.6 mm, 80 parts (31 on the bottom side), 18 nets.

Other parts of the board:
U$1: SFE_LOGO_FLAME_.1
U$2: #_12VIN#0
U$3, U$10: #_EN#0
U$4, U$5: #GND_#0
U$6: #_TX#0
U$7: #_RX#0
U$8, U$9, U$14, U$18: #_GND#0
U$11, U$19: #_3V3#0
U$12: #RX_#0
U$13: #SDA#TX_#0
U$15, U$36: #_SCL#0
U$16: #PWM#0
U$17: #P_#0
U$20, U$35: #_SDA#0
U$21, U$22: #_INT#0
U$23: INFINEON_LOGO
U$24: #PSEL#0
U$25: CO2_SENSOR0
U$26: SFE_LOGO_FLAME_STOP_.1
U$27: #I�C#0
U$28: #PWR#0
U$29: PWR0
U$30: ORDERING_INSTRUCTIONS
U$31: #I#0
U$32: #U#0
U$33: #12VI_#0
U$34: #_PWM#0
U$37: PHOTOACOUSTIC0
U$38: SPECTROSCOPY0
U$39: PASCO2V010

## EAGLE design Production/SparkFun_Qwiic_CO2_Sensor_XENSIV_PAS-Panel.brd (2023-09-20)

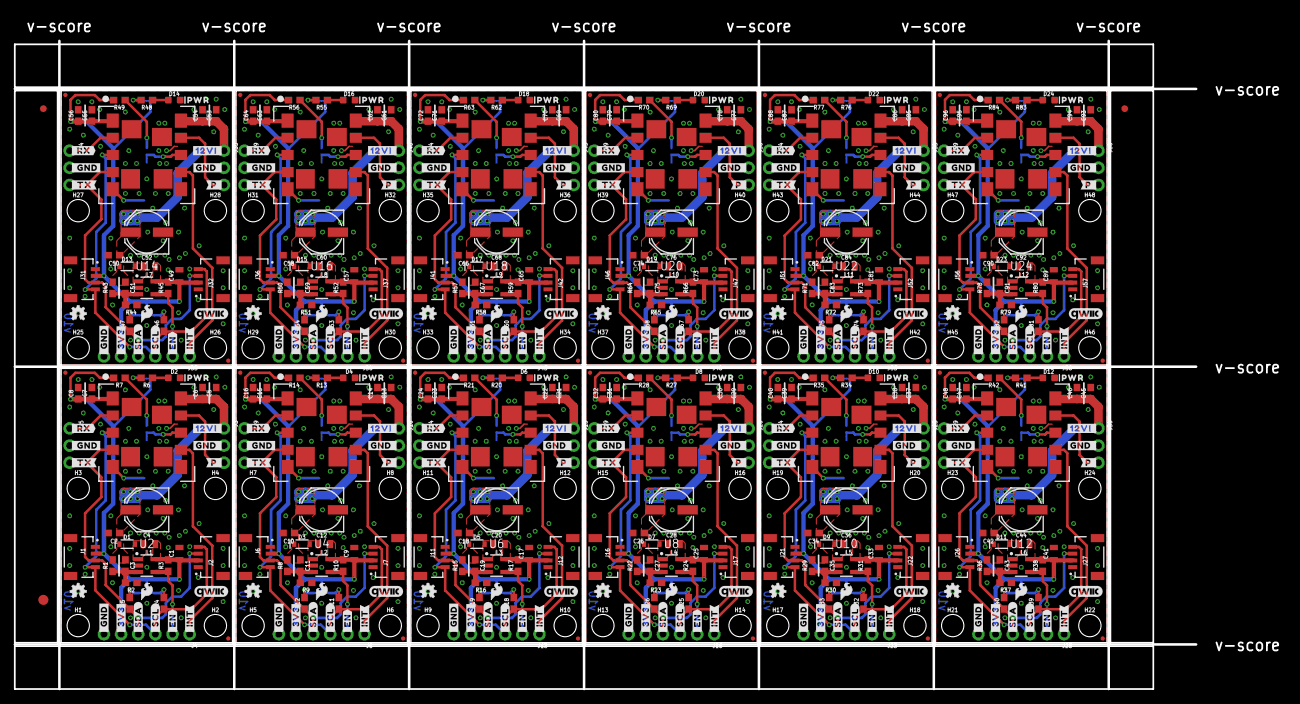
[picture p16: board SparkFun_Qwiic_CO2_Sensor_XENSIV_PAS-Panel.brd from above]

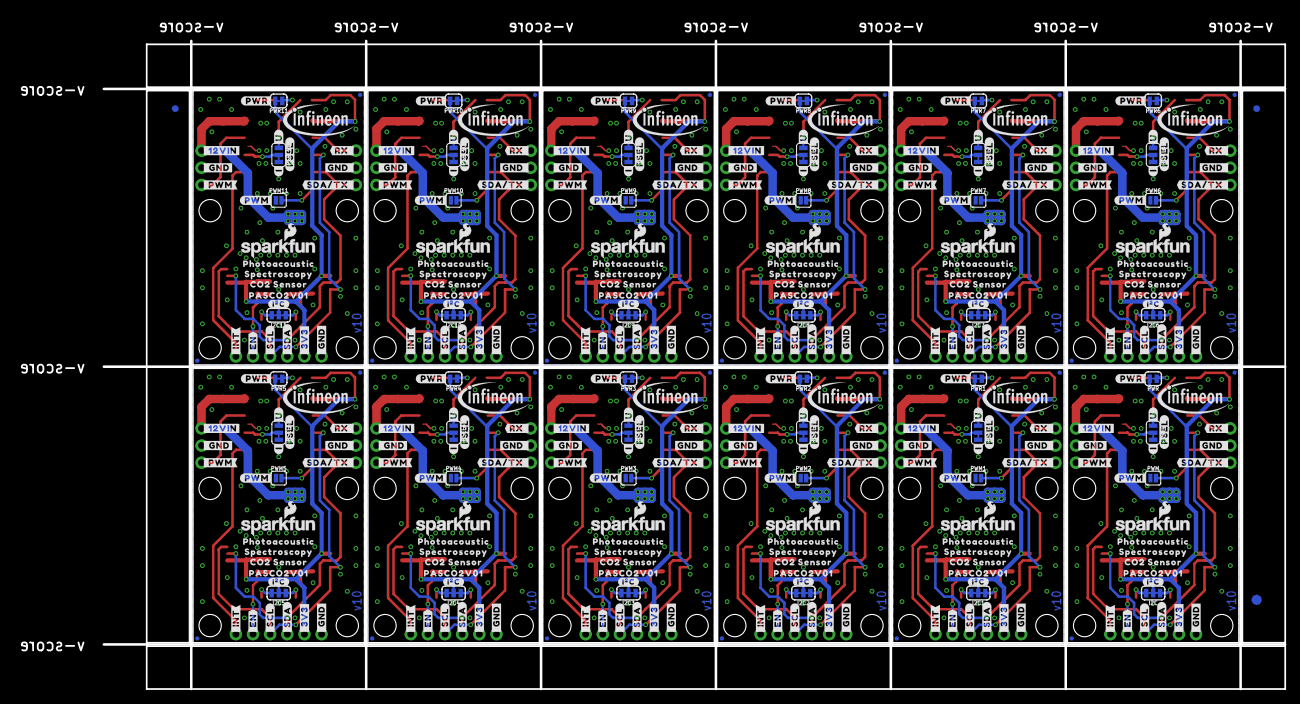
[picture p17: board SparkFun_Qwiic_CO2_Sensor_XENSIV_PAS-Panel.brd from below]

Board: 2 copper layers, 175.0 x 96.0 mm, 942 parts (375 on the bottom side), 216 nets.

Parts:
C1, C9, C17, C25, C33, C41, C49, C57, C65, C73, C81, C89: 10uF; 0805
C2, C8, C10, C16, C18, C24, C26, C32, C34, C40, C42, C48, C50, C56, C58, C64, C66, C72, C74, C80, C82, C88, C90, C96: 4.7uF; 0603
C3, C11, C19, C27, C35, C43, C51, C59, C67, C75, C83, C91: 470pF; 0603
C4, C12, C20, C28, C36, C44, C52, C60, C68, C76, C84, C92: 47uF; PANASONIC_D
C5, C7, C13, C15, C21, C23, C29, C31, C37, C39, C45, C47, C53, C55, C61, C63, C69, C71, C77, C79, C85, C87, C93, C95: 0.1uF; 0603
C6, C14, C22, C30, C38, C46, C54, C62, C70, C78, C86, C94: 10nF; 0603
D1, D3, D5, D7, D9, D11, D13, D15, D17, D19, D21, D23: 0.5A/40V/420mV; SOD-323
D2, D4, D6, D8, D10, D12, D14, D16, D18, D20, D22, D24: LED-0603
E$1, E$2, E$3, E$4: FIDUCIAL-1X2
E$5, E$6: FIDUCIAL-1.5X3
FD1, FD2, FD3, FD4, FD5, FD6, FD7, FD8, FD9, FD10, FD11, FD12, FD13, FD14, FD15, FD16, FD17, FD18, FD19, FD20, FD21, FD22, FD23, FD24, FD25, FD26, FD27, FD28, FD29, FD30, FD31, FD32, FD33, FD34, FD35, FD36, FD37, FD38, FD39, FD40, FD41, FD42, FD43, FD44, FD45, FD46, FD47, FD48: FIDUCIALUFIDUCIAL; FIDUCIAL-MICRO
H1, H2, H3, H4, H5, H6, H7, H8, H9, H10, H11, H12, H13, H14, H15, H16, H17, H18, H19, H20, H21, H22, H23, H24, H25, H26, H27, H28, H29, H30, H31, H32, H33, H34, H35, H36, H37, H38, H39, H40, H41, H42, H43, H44, H45, H46, H47, H48: STAND-OFF
I2C, I2C1, I2C2, I2C3, I2C4, I2C5, I2C6, I2C7, I2C8, I2C9, I2C10, I2C11: JUMPER-SMT_3_2-NC_TRACE_SILK; SMT-JUMPER_3_2-NC_TRACE_SILK
J1, J2, J6, J7, J11, J12, J16, J17, J21, J22, J26, J27, J31, J32, J36, J37, J41, J42, J46, J47, J51, J52, J56, J57: QWIIC_RA; JST04_1MM_RA
J3, J5, J9, J10, J14, J15, J19, J20, J24, J25, J29, J30, J34, J35, J39, J40, J44, J45, J49, J50, J54, J55, J59, J60: 1X03_NO_SILK
J4, J8, J13, J18, J23, J28, J33, J38, J43, J48, J53, J58: 1X06_NO_SILK
L1, L2, L3, L4, L5, L6, L7, L8, L9, L10, L11, L12: 10uH; 0805
LOGO1, LOGO4, LOGO7, LOGO10, LOGO13, LOGO16, LOGO19, LOGO22, LOGO25, LOGO28, LOGO31, LOGO34: SFE_LOGO_NAME_FLAME.1_INCH; SFE_LOGO_NAME_FLAME_.1
LOGO2, LOGO5, LOGO8, LOGO11, LOGO14, LOGO17, LOGO20, LOGO23, LOGO26, LOGO29, LOGO32, LOGO35: QWIIC_LOGO_5MM; QWIIC_5MM
LOGO3, LOGO6, LOGO9, LOGO12, LOGO15, LOGO18, LOGO21, LOGO24, LOGO27, LOGO30, LOGO33, LOGO36: OSHW-LOGOMINI; OSHW-LOGO-MINI
PSEL, PSEL1, PSEL2, PSEL3, PSEL4, PSEL5, PSEL6, PSEL7, PSEL8, PSEL9, PSEL10, PSEL11: JUMPER-SMT_3_1-NC_TRACE_SILK; SMT-JUMPER_3_1-NC_TRACE_SILK
PWM, PWM1, PWM2, PWM3, PWM4, PWM5, PWM6, PWM7, PWM8, PWM9, PWM10, PWM11: JUMPER-SMT_2_NO_SILK; SMT-JUMPER_2_NO_SILK
PWR, PWR1, PWR2, PWR3, PWR4, PWR5, PWR6, PWR7, PWR8, PWR9, PWR10, PWR11: JUMPER-SMT_2_NC_TRACE_SILK; SMT-JUMPER_2_NC_TRACE_SILK
R1, R8, R15, R22, R29, R36, R43, R50, R57, R64, R71, R78: 47k; 0603
R2, R9, R16, R23, R30, R37, R44, R51, R58, R65, R72, R79: 5.62k; 0603
R3, R10, R17, R24, R31, R38, R45, R52, R59, R66, R73, R80: 100k; 0603
R4, R5, R11, R12, R18, R19, R25, R26, R32, R33, R39, R40, R46, R47, R53, R54, R60, R61, R67, R68, R74, R75, R81, R82: 2.2k; 0603
R6, R13, R20, R27, R34, R41, R48, R55, R62, R69, R76, R83: 4.7k; 0603
R7, R14, R21, R28, R35, R42, R49, R56, R63, R70, R77, R84: 10k; 0603
U1, U3, U5, U7, U9, U11, U13, U15, U17, U19, U21, U23: PASCO2V01BUMA1; LG-MLGA-14-1_Z8B00206105
U2, U4, U6, U8, U10, U12, U14, U16, U18, U20, U22, U24: AP3012; SOT95P280X145-5M
U$1, U$30, U$77, U$115, U$153, U$191, U$229, U$267, U$305, U$343, U$381, U$419: SFE_LOGO_FLAME_.1
U$2, U$61, U$99, U$137, U$175, U$213, U$251, U$289, U$327, U$365, U$403, U$441: #_12VIN#0
U$3, U$10, U$62, U$63, U$100, U$101, U$138, U$139, U$176, U$177, U$214, U$215, U$252, U$253, U$290, U$291, U$328, U$329, U$366, U$367, U$404, U$405, U$442, U$443: #_EN#0
U$4, U$5, U$40, U$41, U$78, U$79, U$116, U$117, U$154, U$155, U$192, U$193, U$230, U$231, U$268, U$269, U$306, U$307, U$344, U$345, U$382, U$383, U$420, U$421: #GND_#0
U$6, U$42, U$80, U$118, U$156, U$194, U$232, U$270, U$308, U$346, U$384, U$422: #_TX#0
U$7, U$43, U$81, U$119, U$157, U$195, U$233, U$271, U$309, U$347, U$385, U$423: #_RX#0
U$8, U$9, U$14, U$18, U$44, U$45, U$48, U$50, U$82, U$83, U$86, U$88, U$120, U$121, U$124, U$126, U$158, U$159, U$162, U$164, U$196, U$197, U$200, U$202, U$234, U$235, U$238, U$240, U$272, U$273, U$276, U$278, U$310, U$311, U$314, U$316, U$348, U$349, U$352, U$354, U$386, U$387, U$390, U$392, U$424, U$425, U$428, U$430: #_GND#0
U$11, U$19, U$51, U$64, U$89, U$102, U$127, U$140, U$165, U$178, U$203, U$216, U$241, U$254, U$279, U$292, U$317, U$330, U$355, U$368, U$393, U$406, U$431, U$444: #_3V3#0
U$12, U$46, U$84, U$122, U$160, U$198, U$236, U$274, U$312, U$350, U$388, U$426: #RX_#0
U$13, U$47, U$85, U$123, U$161, U$199, U$237, U$275, U$313, U$351, U$389, U$427: #SDA#TX_#0
U$15, U$36, U$49, U$71, U$87, U$109, U$125, U$147, U$163, U$185, U$201, U$223, U$239, U$261, U$277, U$299, U$315, U$337, U$353, U$375, U$391, U$413, U$429, U$451: #_SCL#0
U$16, U$67, U$105, U$143, U$181, U$219, U$257, U$295, U$333, U$371, U$409, U$447: #PWM#0
U$17, U$65, U$103, U$141, U$179, U$217, U$255, U$293, U$331, U$369, U$407, U$445: #P_#0
U$20, U$35, U$69, U$70, U$107, U$108, U$145, U$146, U$183, U$184, U$221, U$222, U$259, U$260, U$297, U$298, U$335, U$336, U$373, U$374, U$411, U$412, U$449, U$450: #_SDA#0
U$21, U$22, U$52, U$53, U$90, U$91, U$128, U$129, U$166, U$167, U$204, U$205, U$242, U$243, U$280, U$281, U$318, U$319, U$356, U$357, U$394, U$395, U$432, U$433: #_INT#0
U$23, U$76, U$114, U$152, U$190, U$228, U$266, U$304, U$342, U$380, U$418, U$456: INFINEON_LOGO
U$24, U$54, U$92, U$130, U$168, U$206, U$244, U$282, U$320, U$358, U$396, U$434: #PSEL#0
U$25, U$74, U$112, U$150, U$188, U$226, U$264, U$302, U$340, U$378, U$416, U$454: CO2_SENSOR0
U$26, U$56, U$94, U$132, U$170, U$208, U$246, U$284, U$322, U$360, U$398, U$436: SFE_LOGO_FLAME_STOP_.1
U$27, U$55, U$93, U$131, U$169, U$207, U$245, U$283, U$321, U$359, U$397, U$435: #I�C#0
U$28, U$68, U$106, U$144, U$182, U$220, U$258, U$296, U$334, U$372, U$410, U$448: #PWR#0
U$29, U$57, U$95, U$133, U$171, U$209, U$247, U$285, U$323, U$361, U$399, U$437: PWR0
U$31, U$59, U$97, U$135, U$173, U$211, U$249, U$287, U$325, U$363, U$401, U$439: #I#0
U$32, U$58, U$96, U$134, U$172, U$210, U$248, U$286, U$324, U$362, U$400, U$438: #U#0
U$33, U$60, U$98, U$136, U$174, U$212, U$250, U$288, U$326, U$364, U$402, U$440: #12VI_#0
U$34, U$66, U$104, U$142, U$180, U$218, U$256, U$294, U$332, U$370, U$408, U$446: #_PWM#0
U$37, U$72, U$110, U$148, U$186, U$224, U$262, U$300, U$338, U$376, U$414, U$452: PHOTOACOUSTIC0
U$38, U$73, U$111, U$149, U$187, U$225, U$263, U$301, U$339, U$377, U$415, U$453: SPECTROSCOPY0
U$39, U$75, U$113, U$151, U$189, U$227, U$265, U$303, U$341, U$379, U$417, U$455: PASCO2V010

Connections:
3.3V: C1.1, C7.1, C8.1, I2C.2, J1.2, J2.2, J4.5, L1.1, PWR.2, R3.2, R7.2, U1.1, U2.5
3.3V1: C9.1, C15.1, C16.1, I2C1.2, J6.2, J7.2, J8.5, L2.1, PWR1.2, R10.2, R14.2, U3.1, U4.5
3.3V2: C17.1, C23.1, C24.1, I2C2.2, J11.2, J12.2, J13.5, L3.1, PWR2.2, R17.2, R21.2, U5.1, U6.5
3.3V3: C25.1, C31.1, C32.1, I2C3.2, J16.2, J17.2, J18.5, L4.1, PWR3.2, R24.2, R28.2, U7.1, U8.5
3.3V4: C33.1, C39.1, C40.1, I2C4.2, J21.2, J22.2, J23.5, L5.1, PWR4.2, R31.2, R35.2, U9.1, U10.5
3.3V5: C41.1, C47.1, C48.1, I2C5.2, J26.2, J27.2, J28.5, L6.1, PWR5.2, R38.2, R42.2, U11.1, U12.5
3.3V6: C49.1, C55.1, C56.1, I2C6.2, J31.2, J32.2, J33.5, L7.1, PWR6.2, R45.2, R49.2, U13.1, U14.5
3.3V7: C57.1, C63.1, C64.1, I2C7.2, J36.2, J37.2, J38.5, L8.1, PWR7.2, R52.2, R56.2, U15.1, U16.5
3.3V8: C65.1, C71.1, C72.1, I2C8.2, J41.2, J42.2, J43.5, L9.1, PWR8.2, R59.2, R63.2, U17.1, U18.5
3.3V9: C73.1, C79.1, C80.1, I2C9.2, J46.2, J47.2, J48.5, L10.1, PWR9.2, R66.2, R70.2, U19.1, U20.5
3.3V10: C81.1, C87.1, C88.1, I2C10.2, J51.2, J52.2, J53.5, L11.1, PWR10.2, R73.2, R77.2, U21.1, U22.5
3.3V11: C89.1, C95.1, C96.1, I2C11.2, J56.2, J57.2, J58.5, L12.1, PWR11.2, R80.2, R84.2, U23.1, U24.5
12V: C2.1, C3.1, C4.+, C5.1, C6.1, D1.C, J3.1, R1.2, U1.10
12V1: C10.1, C11.1, C12.+, C13.1, C14.1, D3.C, J10.1, R8.2, U3.10
12V2: C18.1, C19.1, C20.+, C21.1, C22.1, D5.C, J15.1, R15.2, U5.10
12V3: C26.1, C27.1, C28.+, C29.1, C30.1, D7.C, J20.1, R22.2, U7.10
12V4: C34.1, C35.1, C36.+, C37.1, C38.1, D9.C, J25.1, R29.2, U9.10
12V5: C42.1, C43.1, C44.+, C45.1, C46.1, D11.C, J30.1, R36.2, U11.10
12V6: C50.1, C51.1, C52.+, C53.1, C54.1, D13.C, J35.1, R43.2, U13.10
12V7: C58.1, C59.1, C60.+, C61.1, C62.1, D15.C, J40.1, R50.2, U15.10
12V8: C66.1, C67.1, C68.+, C69.1, C70.1, D17.C, J45.1, R57.2, U17.10
12V9: C74.1, C75.1, C76.+, C77.1, C78.1, D19.C, J50.1, R64.2, U19.10
12V10: C82.1, C83.1, C84.+, C85.1, C86.1, D21.C, J55.1, R71.2, U21.10
12V11: C90.1, C91.1, C92.+, C93.1, C94.1, D23.C, J60.1, R78.2, U23.10
EN: J4.2, R3.1, U2.4
EN1: J8.2, R10.1, U4.4
EN2: J13.2, R17.1, U6.4
EN3: J18.2, R24.1, U8.4
EN4: J23.2, R31.1, U10.4
EN5: J28.2, R38.1, U12.4
EN6: J33.2, R45.1, U14.4
EN7: J38.2, R52.1, U16.4
EN8: J43.2, R59.1, U18.4
EN9: J48.2, R66.1, U20.4
EN10: J53.2, R73.1, U22.4
EN11: J58.2, R80.1, U24.4
GND: C1.2, C2.2, C4.-, C5.2, C6.2, C7.2, C8.2, D2.C, J1.1, J2.1, J3.2, J4.6, J5.2, PSEL.3, PWM.1, R2.1, U1.6, U1.11, U1.12, U1.13, U1.14, U2.2
GND1: C9.2, C10.2, C12.-, C13.2, C14.2, C15.2, C16.2, D4.C, J6.1, J7.1, J8.6, J9.2, J10.2, PSEL1.3, PWM1.1, R9.1, U3.6, U3.11, U3.12, U3.13, U3.14, U4.2
GND2: C17.2, C18.2, C20.-, C21.2, C22.2, C23.2, C24.2, D6.C, J11.1, J12.1, J13.6, J14.2, J15.2, PSEL2.3, PWM2.1, R16.1, U5.6, U5.11, U5.12, U5.13, U5.14, U6.2
GND3: C25.2, C26.2, C28.-, C29.2, C30.2, C31.2, C32.2, D8.C, J16.1, J17.1, J18.6, J19.2, J20.2, PSEL3.3, PWM3.1, R23.1, U7.6, U7.11, U7.12, U7.13, U7.14, U8.2
GND4: C33.2, C34.2, C36.-, C37.2, C38.2, C39.2, C40.2, D10.C, J21.1, J22.1, J23.6, J24.2, J25.2, PSEL4.3, PWM4.1, R30.1, U9.6, U9.11, U9.12, U9.13, U9.14, U10.2
GND5: C41.2, C42.2, C44.-, C45.2, C46.2, C47.2, C48.2, D12.C, J26.1, J27.1, J28.6, J29.2, J30.2, PSEL5.3, PWM5.1, R37.1, U11.6, U11.11, U11.12, U11.13, U11.14, U12.2
GND6: C49.2, C50.2, C52.-, C53.2, C54.2, C55.2, C56.2, D14.C, J31.1, J32.1, J33.6, J34.2, J35.2, PSEL6.3, PWM6.1, R44.1, U13.6, U13.11, U13.12, U13.13, U13.14, U14.2
GND7: C57.2, C58.2, C60.-, C61.2, C62.2, C63.2, C64.2, D16.C, J36.1, J37.1, J38.6, J39.2, J40.2, PSEL7.3, PWM7.1, R51.1, U15.6, U15.11, U15.12, U15.13, U15.14, U16.2
GND8: C65.2, C66.2, C68.-, C69.2, C70.2, C71.2, C72.2, D18.C, J41.1, J42.1, J43.6, J44.2, J45.2, PSEL8.3, PWM8.1, R58.1, U17.6, U17.11, U17.12, U17.13, U17.14, U18.2
GND9: C73.2, C74.2, C76.-, C77.2, C78.2, C79.2, C80.2, D20.C, J46.1, J47.1, J48.6, J49.2, J50.2, PSEL9.3, PWM9.1, R65.1, U19.6, U19.11, U19.12, U19.13, U19.14, U20.2
GND10: C81.2, C82.2, C84.-, C85.2, C86.2, C87.2, C88.2, D22.C, J51.1, J52.1, J53.6, J54.2, J55.2, PSEL10.3, PWM10.1, R72.1, U21.6, U21.11, U21.12, U21.13, U21.14, U22.2
GND11: C89.2, C90.2, C92.-, C93.2, C94.2, C95.2, C96.2, D24.C, J56.1, J57.1, J58.6, J59.2, J60.2, PSEL11.3, PWM11.1, R79.1, U23.6, U23.11, U23.12, U23.13, U23.14, U24.2
I2C_INT: J4.1, U1.7
I2C_INT1: J8.1, U3.7
I2C_INT2: J13.1, U5.7
I2C_INT3: J18.1, U7.7
I2C_INT4: J23.1, U9.7
I2C_INT5: J28.1, U11.7
I2C_INT6: J33.1, U13.7
I2C_INT7: J38.1, U15.7
I2C_INT8: J43.1, U17.7
I2C_INT9: J48.1, U19.7
I2C_INT10: J53.1, U21.7
I2C_INT11: J58.1, U23.7
unnamed: I2C.1, R5.2
unnamed: D1.A, L1.2, U2.1
unnamed: I2C.3, R4.2
unnamed: C3.2, R1.1, R2.2, U2.3
unnamed: PSEL.2, U1.8
unnamed: D2.A, R6.1
unnamed: PWR.1, R6.2
unnamed: PSEL.1, R7.1
unnamed: PWM.2, U1.5
unnamed: D3.A, L2.2, U4.1
unnamed: C11.2, R8.1, R9.2, U4.3
unnamed: I2C1.1, R12.2
unnamed: I2C1.3, R11.2
unnamed: PSEL1.2, U3.8
unnamed: D4.A, R13.1
unnamed: PWR1.1, R13.2
unnamed: PSEL1.1, R14.1
unnamed: PWM1.2, U3.5
unnamed: D5.A, L3.2, U6.1
unnamed: C19.2, R15.1, R16.2, U6.3
unnamed: I2C2.1, R19.2
unnamed: I2C2.3, R18.2
unnamed: PSEL2.2, U5.8
unnamed: D6.A, R20.1
unnamed: PWR2.1, R20.2
unnamed: PSEL2.1, R21.1
unnamed: PWM2.2, U5.5
unnamed: D7.A, L4.2, U8.1
unnamed: C27.2, R22.1, R23.2, U8.3
unnamed: I2C3.1, R26.2
unnamed: I2C3.3, R25.2
unnamed: PSEL3.2, U7.8
unnamed: D8.A, R27.1
unnamed: PWR3.1, R27.2
unnamed: PSEL3.1, R28.1
unnamed: PWM3.2, U7.5
unnamed: D9.A, L5.2, U10.1
unnamed: C35.2, R29.1, R30.2, U10.3
unnamed: I2C4.1, R33.2
unnamed: I2C4.3, R32.2
unnamed: PSEL4.2, U9.8
unnamed: D10.A, R34.1
unnamed: PWR4.1, R34.2
unnamed: PSEL4.1, R35.1
unnamed: PWM4.2, U9.5
unnamed: D11.A, L6.2, U12.1
unnamed: C43.2, R36.1, R37.2, U12.3
unnamed: I2C5.1, R40.2
unnamed: I2C5.3, R39.2
unnamed: PSEL5.2, U11.8
unnamed: D12.A, R41.1
unnamed: PWR5.1, R41.2
unnamed: PSEL5.1, R42.1
unnamed: PWM5.2, U11.5
unnamed: D13.A, L7.2, U14.1
unnamed: C51.2, R43.1, R44.2, U14.3
unnamed: I2C6.1, R47.2
unnamed: I2C6.3, R46.2
unnamed: PSEL6.2, U13.8
unnamed: D14.A, R48.1
unnamed: PWR6.1, R48.2
unnamed: PSEL6.1, R49.1
unnamed: PWM6.2, U13.5
unnamed: D15.A, L8.2, U16.1
unnamed: C59.2, R50.1, R51.2, U16.3
unnamed: I2C7.1, R54.2
unnamed: I2C7.3, R53.2
unnamed: PSEL7.2, U15.8
unnamed: D16.A, R55.1
unnamed: PWR7.1, R55.2
unnamed: PSEL7.1, R56.1
unnamed: PWM7.2, U15.5
unnamed: D17.A, L9.2, U18.1
unnamed: C67.2, R57.1, R58.2, U18.3
unnamed: I2C8.1, R61.2
unnamed: I2C8.3, R60.2
unnamed: PSEL8.2, U17.8
unnamed: D18.A, R62.1
unnamed: PWR8.1, R62.2
unnamed: PSEL8.1, R63.1
unnamed: PWM8.2, U17.5
unnamed: D19.A, L10.2, U20.1
unnamed: C75.2, R64.1, R65.2, U20.3
unnamed: I2C9.1, R68.2
unnamed: I2C9.3, R67.2
unnamed: PSEL9.2, U19.8
unnamed: D20.A, R69.1
unnamed: PWR9.1, R69.2
unnamed: PSEL9.1, R70.1
unnamed: PWM9.2, U19.5
unnamed: D21.A, L11.2, U22.1
unnamed: C83.2, R71.1, R72.2, U22.3
unnamed: I2C10.1, R75.2
unnamed: I2C10.3, R74.2
unnamed: PSEL10.2, U21.8
unnamed: D22.A, R76.1
unnamed: PWR10.1, R76.2
unnamed: PSEL10.1, R77.1
unnamed: PWM10.2, U21.5
unnamed: D23.A, L12.2, U24.1
unnamed: C91.2, R78.1, R79.2, U24.3
unnamed: I2C11.1, R82.2
unnamed: I2C11.3, R81.2
unnamed: PSEL11.2, U23.8
unnamed: D24.A, R83.1
unnamed: PWR11.1, R83.2
unnamed: PSEL11.1, R84.1
unnamed: PWM11.2, U23.5
PWM_OUT: J3.3, U1.9
PWM_OUT1: J10.3, U3.9
PWM_OUT2: J15.3, U5.9
PWM_OUT3: J20.3, U7.9
PWM_OUT4: J25.3, U9.9
PWM_OUT5: J30.3, U11.9
PWM_OUT6: J35.3, U13.9
PWM_OUT7: J40.3, U15.9
PWM_OUT8: J45.3, U17.9
PWM_OUT9: J50.3, U19.9
PWM_OUT10: J55.3, U21.9
PWM_OUT11: J60.3, U23.9
RX: J5.1, U1.2
RX1: J9.1, U3.2
RX2: J14.1, U5.2
RX3: J19.1, U7.2
RX4: J24.1, U9.2
RX5: J29.1, U11.2
RX6: J34.1, U13.2
RX7: J39.1, U15.2
RX8: J44.1, U17.2
RX9: J49.1, U19.2
RX10: J54.1, U21.2
RX11: J59.1, U23.2
SCL: J1.4, J2.4, J4.3, R4.1, U1.3
SCL1: J6.4, J7.4, J8.3, R11.1, U3.3
SCL2: J11.4, J12.4, J13.3, R18.1, U5.3
SCL3: J16.4, J17.4, J18.3, R25.1, U7.3
SCL4: J21.4, J22.4, J23.3, R32.1, U9.3
SCL5: J26.4, J27.4, J28.3, R39.1, U11.3
SCL6: J31.4, J32.4, J33.3, R46.1, U13.3
SCL7: J36.4, J37.4, J38.3, R53.1, U15.3
SCL8: J41.4, J42.4, J43.3, R60.1, U17.3
SCL9: J46.4, J47.4, J48.3, R67.1, U19.3
SCL10: J51.4, J52.4, J53.3, R74.1, U21.3
SCL11: J56.4, J57.4, J58.3, R81.1, U23.3
SDA/TX: J1.3, J2.3, J4.4, J5.3, R5.1, U1.4
SDA/TX1: J6.3, J7.3, J8.4, J9.3, R12.1, U3.4
SDA/TX2: J11.3, J12.3, J13.4, J14.3, R19.1, U5.4
SDA/TX3: J16.3, J17.3, J18.4, J19.3, R26.1, U7.4
SDA/TX4: J21.3, J22.3, J23.4, J24.3, R33.1, U9.4
SDA/TX5: J26.3, J27.3, J28.4, J29.3, R40.1, U11.4
SDA/TX6: J31.3, J32.3, J33.4, J34.3, R47.1, U13.4
SDA/TX7: J36.3, J37.3, J38.4, J39.3, R54.1, U15.4
SDA/TX8: J41.3, J42.3, J43.4, J44.3, R61.1, U17.4
SDA/TX9: J46.3, J47.3, J48.4, J49.3, R68.1, U19.4
SDA/TX10: J51.3, J52.3, J53.4, J54.3, R75.1, U21.4
SDA/TX11: J56.3, J57.3, J58.4, J59.3, R82.1, U23.4

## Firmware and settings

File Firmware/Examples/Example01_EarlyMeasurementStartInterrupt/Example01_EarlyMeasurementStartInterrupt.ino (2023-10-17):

/*
 *  Name: Example01_EarlyMeasurementStartInterrupt
 *
 *  By: SparkFun Electronics, based on code from Infineon
 * 
 *  SPDX-License-Identifier: MIT
 *
 *
 *  Description: 
 *  This example is based on the early notification example from Infineon's 
 *  `arduino-pas-co2-sensor` library. The biggest deviation is to make it 
 *  specific to the ESP32 Thing Plus C. This example interfaces the interrupt
 *  pin of the ESP32 Thing Plus C for readout synch and ties the INT pin to the
 *  EN pin on the Qwiic PASCO2V01 board.
 *
 *  Please see examples/XENSIV PAS CO2/early-notification for more details.
 * 
 *  Feel like supporting open source hardware?
 *  Buy a board from SparkFun!
 *  SparkFun Photoacoustic Spectroscopy CO2 Sensor - PASCO2V01 (Qwiic) (SEN-22956) https://www.sparkfun.com/products/22956
 *  SparkFun IoT RedBoard - ESP32 Development Board (WRL-19177) https://www.sparkfun.com/products/19177
 *
 *  Hardware connections:
 *  Connect the qwiic connector between the ESP32 Thing Plus C and the Qwiic PASCO2V01.
 *  Need a qwiic cable? Get one here: https://www.sparkfun.com/products/17260
 *  Using a breadboard, connect a jumper between the INT and EN pins, then 
 *    connect it to pin 12 on the ESP32 Thing Plus C.
 *
 */

#include <Arduino.h>
#include <pas-co2-ino.hpp> // http://librarymanager/All#XENSIV_PAS_CO2

uint8_t intPin = 13; // ESP32 Thing Plus C pin, change for your hardware.

#define I2C_FREQ_HZ 400000
#define PERIODIC_MEAS_INTERVAL_IN_SECONDS 10
#define EARLY_NOTIFICATION_ENABLED true

PASCO2Ino myCO2Sensor(&Wire, intPin);

int16_t co2ppm;
Error_t err;

/* 
 * ISR will be called when the sensor is about start performing a measurement 
 * and when it's completed. This will allow the main loop to read the 
 * measurement when one is ready.
 */
volatile bool measurementReady = false;
void isr (void *) {
  if (digitalRead(intPin) == LOW)
    measurementReady = true;
  else
    measurementReady = false;
}

void setup() {
  Serial.begin(115200);
  
  // Wait for serial to open.
  while(!Serial) {
    delay(100);
  }

  // Start I2C.
  Wire.begin();
  Wire.setClock(I2C_FREQ_HZ);

  // Initialize the sensor.
  err = myCO2Sensor.begin();
  if(XENSIV_PASCO2_OK != err) {
    Serial.print("Initialization error: ");
    Serial.println(err);
  }

  // Start measurement every 10s, no alarm set, pass in the ISR, and enable early notification.
  err = myCO2Sensor.startMeasure(PERIODIC_MEAS_INTERVAL_IN_SECONDS, 0, isr, EARLY_NOTIFICATION_ENABLED);
  if(XENSIV_PASCO2_OK != err){
    Serial.print("Start measurement error: ");
    Serial.println(err);
  }

  Serial.println("Sensor setup complete and measurement started successfully.");

}

void loop() {
  if (measurementReady) {
    
    // Clear flag
    measurementReady = false;

    Serial.println("Measurement ready.");

    err = myCO2Sensor.getCO2(co2ppm);
    if(XENSIV_PASCO2_OK != err){
      Serial.print("CO2 measure error: ");
      Serial.println(err);
    }

    Serial.print("CO2 PPM value: ");
    Serial.println(co2ppm);
  }

}

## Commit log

2023-07-07 Added v01 files.
    [SparkFun_Qwiic_CO2_Sensor_XENSIV_PAS.brd, SparkFun_Qwiic_CO2_Sensor_XENSIV_PAS.sch]
2023-07-10 Update pre design review
    Add keepouts for exposed pads.
    Move vias to avoid keepouts.
    Add 10k PUR to PSEL 3.3V selector.
    Add voltage/current details to CO2 sensor on schematic.
    Modified bottom PTHs to match standard order.
    Move vias for ground pour.
    Remove ground stub and unnecessary tRestrict.
    [SparkFun_Qwiic_CO2_Sensor_XENSIV_PAS.brd, SparkFun_Qwiic_CO2_Sensor_XENSIV_PAS.sch]
2023-07-10 Update ordering instructions.
    [SparkFun_Qwiic_CO2_Sensor_XENSIV_PAS.brd]
2023-07-10 Post design review changes and gerbers.
    Add tDocu for the can and put squares for PnP.
    Move EN to bottom row.
    Rearrange I2C PTHs on bottom row to align with prior art.
    Add PWM/PWM_DIS breakout.
    Change silk on 12V to 12VIN.
    Shift vertical PTHs down 0.05 to line up with perfboard holes.
    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
    [SparkFun_Qwiic_CO2_Sensor_XENSIV_PAS.GBL, SparkFun_Qwiic_CO2_Sensor_XENSIV_PAS.GBO, SparkFun_Qwiic_CO2_Sensor_XENSIV_PAS.GBP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]
2023-07-31 Update for v10.
    Schematic - Make version v10.
    Board - Make version v10. Change size of Silk title text.
    Production - Removed individual board gerbers, add panel gerbers.
    [SparkFun_Qwiic_CO2_Sensor_XENSIV_PAS-Panel.GBL, SparkFun_Qwiic_CO2_Sensor_XENSIV_PAS-Panel.GBO, SparkFun_Qwiic_CO2_Sensor_XENSIV_PAS-Panel.GBP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]
2023-08-01 Move Flame silk to middle.
    Repanelize after.
    [SparkFun_Qwiic_CO2_Sensor_XENSIV_PAS-Panel.brd, SparkFun_Qwiic_CO2_Sensor_XENSIV_PAS.brd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]
2023-08-16 Docs update
    Updates to Hardware Overview, Hardware Assembly & Troubleshooting
2023-08-22 Docs Update
    Adding examples section basics & minor updates to Assembly & Overview sections.
2023-08-30 Swapped boost regulator.
2023-09-20 BOM change and add logo to silk.
    [SparkFun_Qwiic_CO2_Sensor_XENSIV_PAS-Panel.brd, SparkFun_Qwiic_CO2_Sensor_XENSIV_PAS.brd, SparkFun_Qwiic_CO2_Sensor_XENSIV_PAS.sch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]
2023-10-23 Add calibration document.
2023-10-25 Update docs
    Adding calibration information and other minor updates for release.
2023-10-31 Update hardware_overview.md
    Adding missing I2C jumper description.

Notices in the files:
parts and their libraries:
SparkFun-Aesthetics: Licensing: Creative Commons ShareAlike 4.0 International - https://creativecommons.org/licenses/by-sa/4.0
